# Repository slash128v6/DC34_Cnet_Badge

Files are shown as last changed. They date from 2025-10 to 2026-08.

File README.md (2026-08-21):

# DC34 CompuNet Badge - Malware Scan Tool 3000

Join CompuNet Critical Start at Defcon!

> [!TIP]
> **THIS SPACE FOR LEASE - CALL 702-263-9744 **

# Section 1: Hardware Assembly

1.	Verify inventory:

| Qty	| Description |
|---|---|
|1	|PCB |
|1	|ESP32 Dev Module |
|1	|Round LCD Display |
|1	|RFID Reader |
|1	|Micro SD Card Reader |
|1	|Micro SD Card |
|1	|Slide Switch |
|1	|Schottky Diode |
|1	|RGB LED |
|1	|6 Pin SAO Female Header |
|1	|Battery Holder |
|4	|AAA Batteries |
|1	|Foam Tape |
|1  |3d Printed Stand |
|5  |3d Printed "Slides" |
|5  |RFID Sticker Tags |

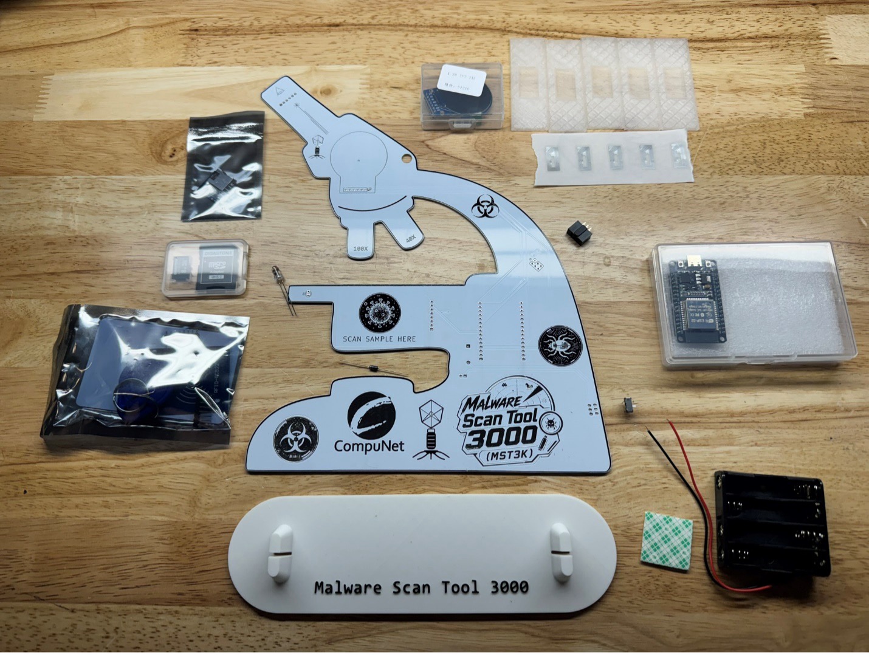
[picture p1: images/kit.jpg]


2.	If you haven't, please download the repo for documentation and code:

[https://github.com/slash128v6/DC34_Cnet_Badge](https://github.com/slash128v6/DC34_Cnet_Badge)

3.	Bend the legs on the Schottky diode and solder on the back side of the PCB. Note the polarity band. Trim the leads on the front of the PCB.

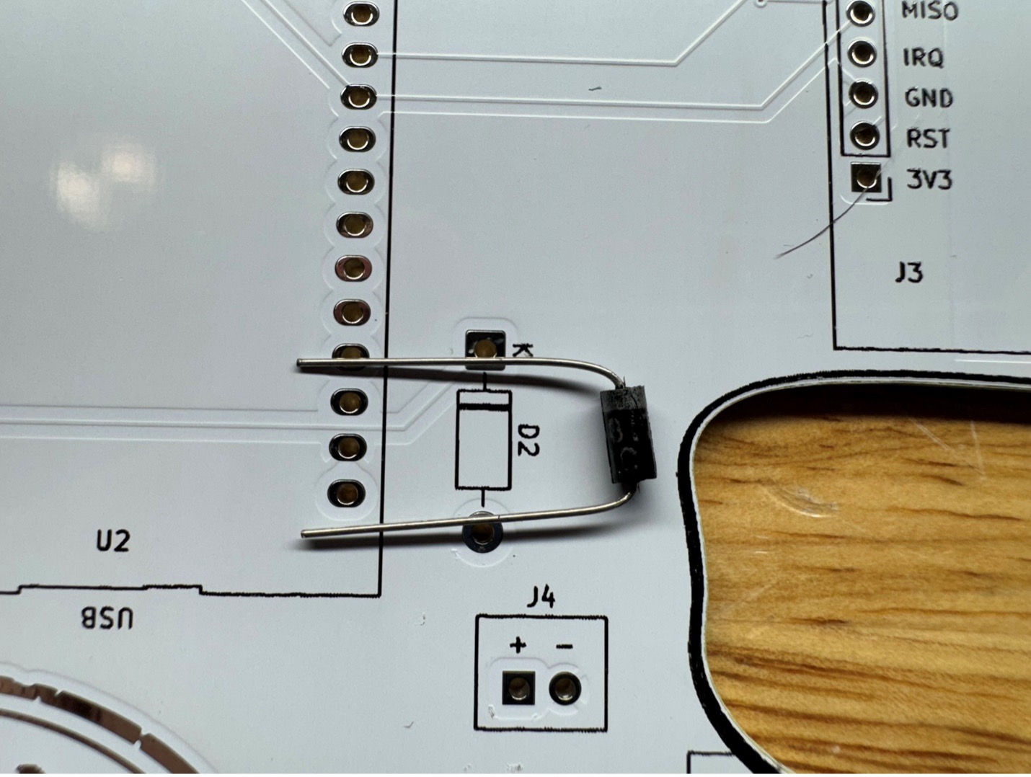
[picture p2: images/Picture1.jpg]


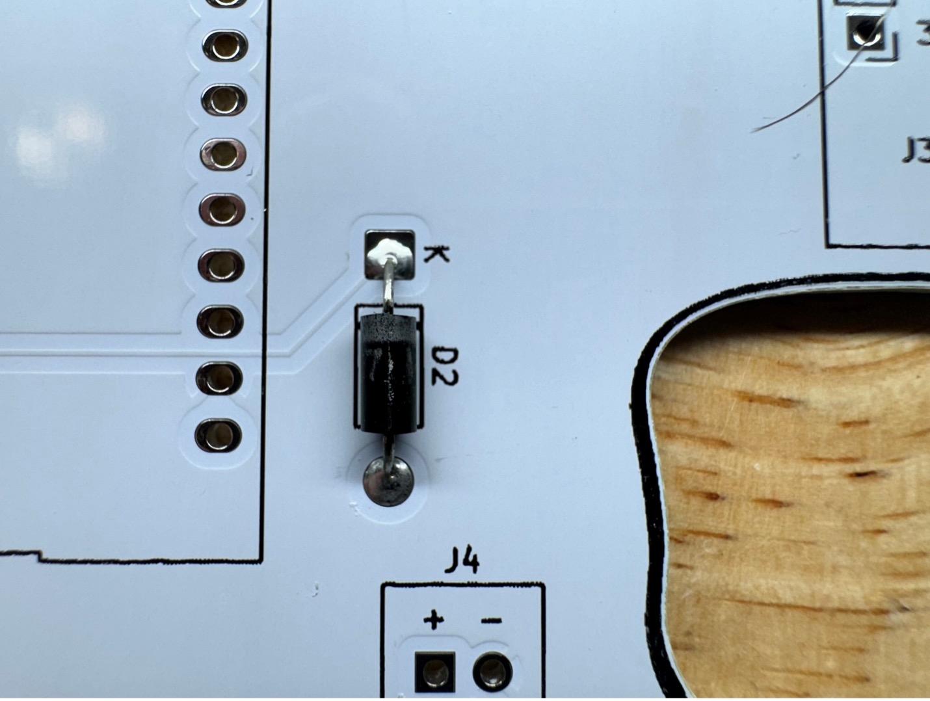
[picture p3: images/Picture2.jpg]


4.	Solder the slide switch on the back of the PCB

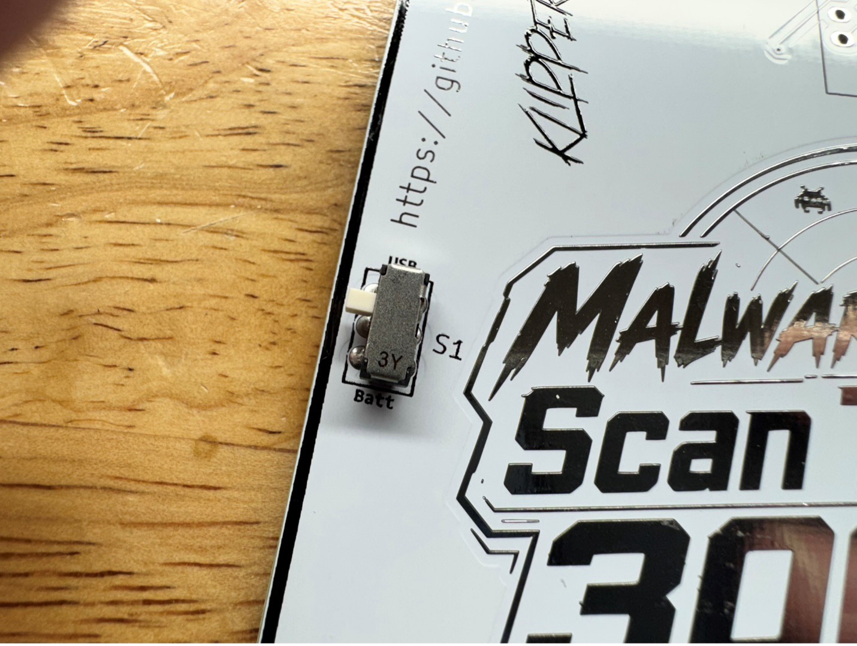
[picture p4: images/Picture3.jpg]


5.	Solder the short side of the pin header to the Micro SD Card Reader as shown:

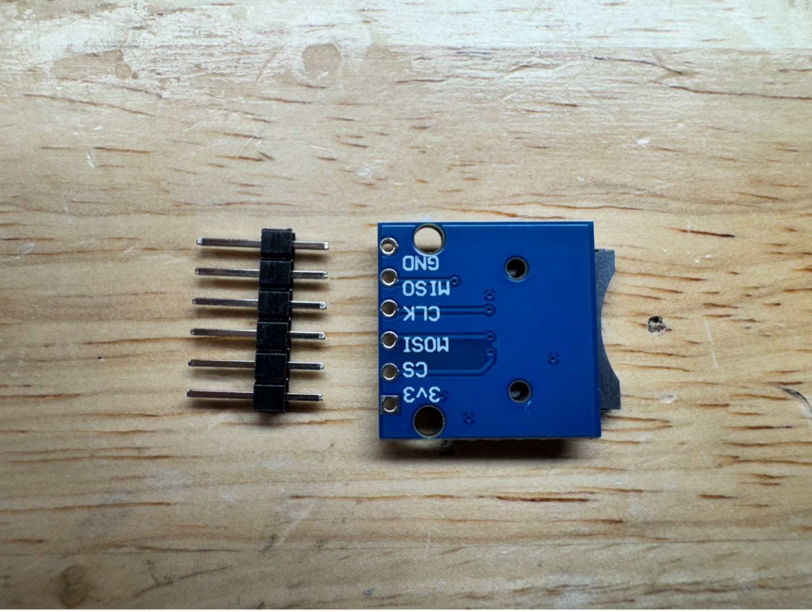
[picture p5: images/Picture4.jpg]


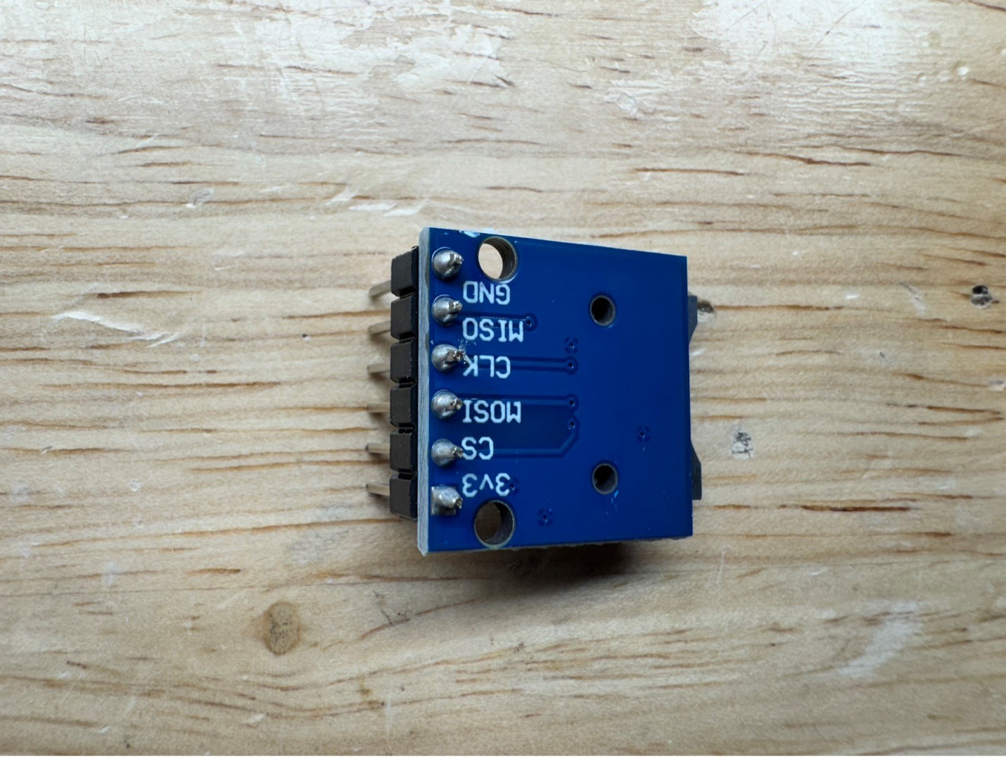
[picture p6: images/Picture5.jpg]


6.	Solder the Micro SD Card Reader to the back of the PCB as shown:

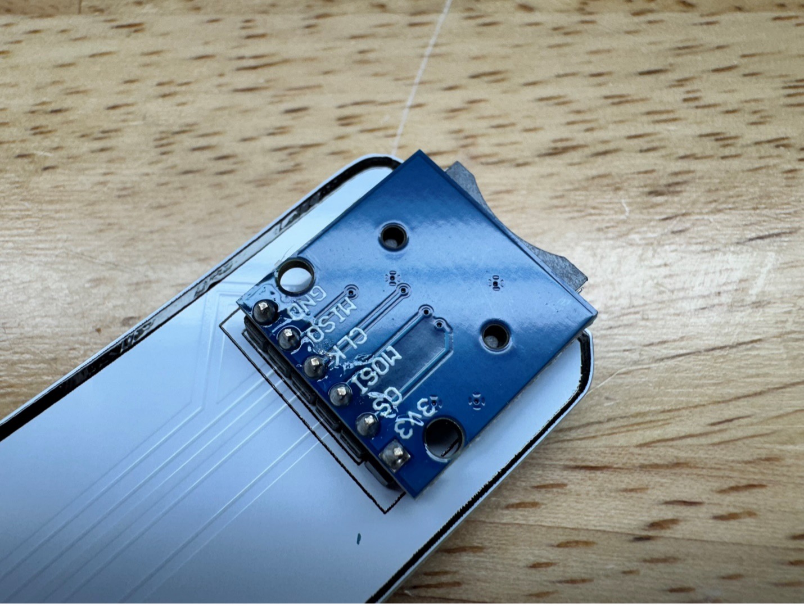
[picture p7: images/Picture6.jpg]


7.	Solder the short side of the pin header to the RFID Reader as shown:

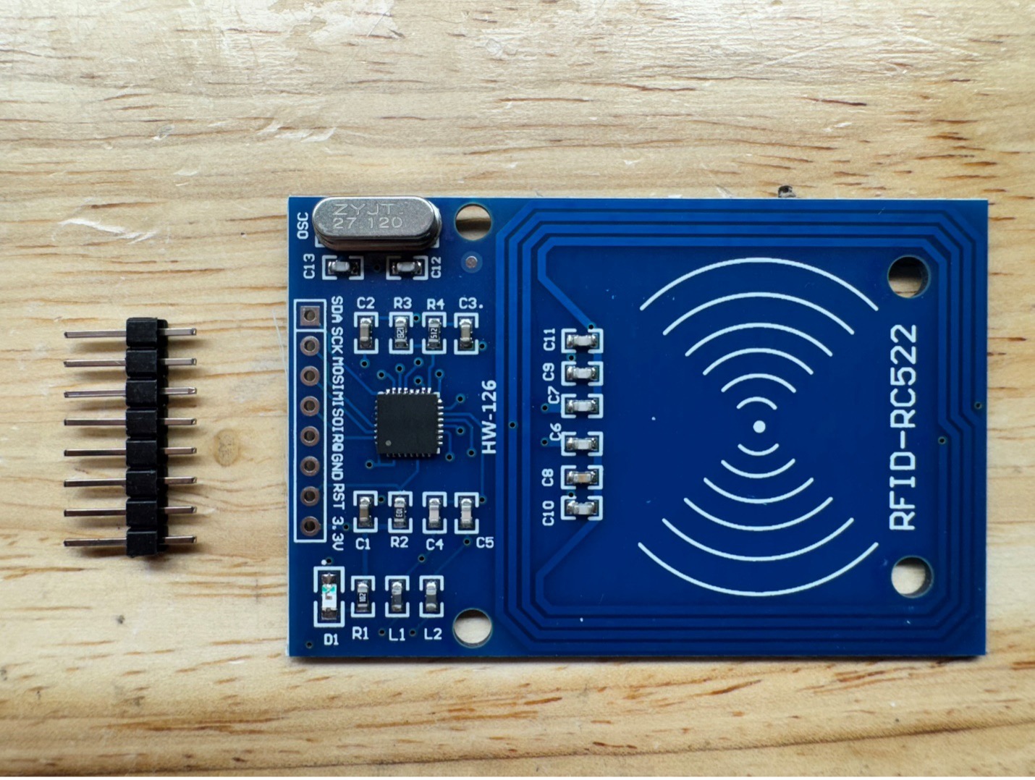
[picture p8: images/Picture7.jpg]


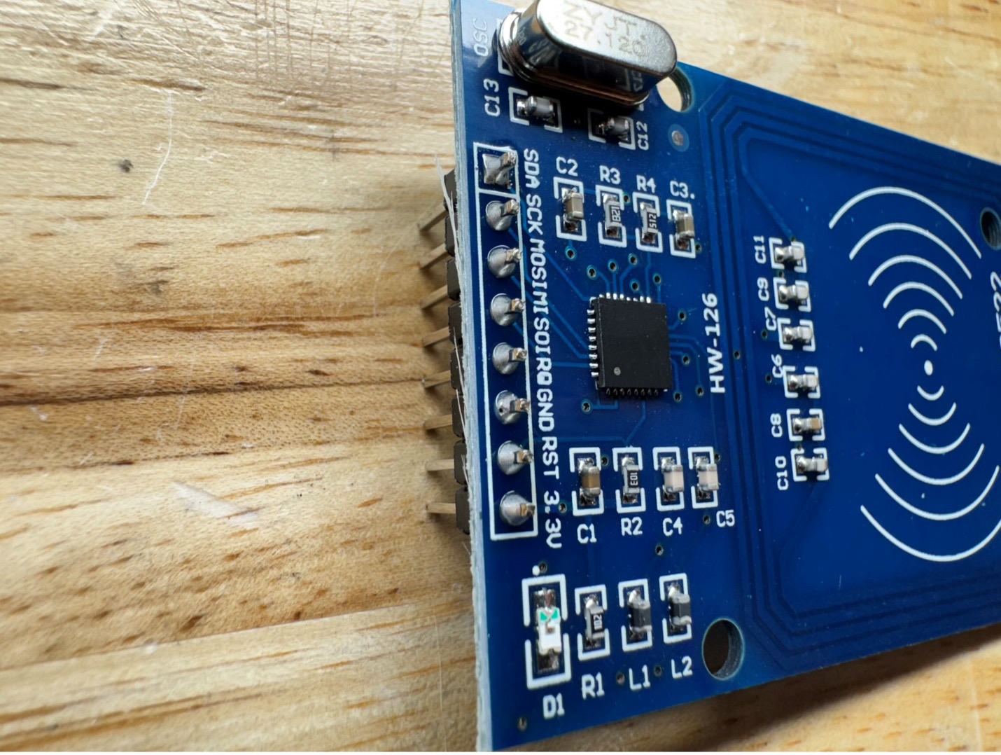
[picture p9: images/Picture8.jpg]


8.  Solder the RFID Reader to the back of the PCB as shown:

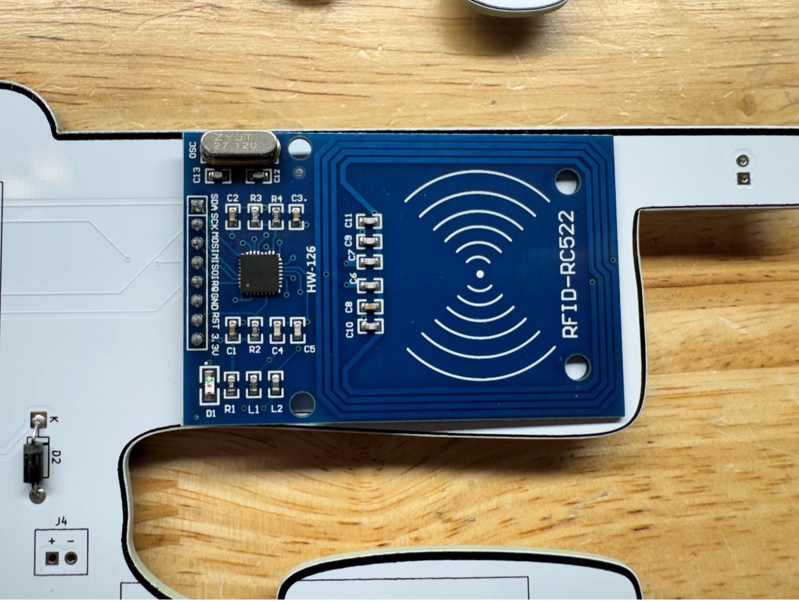
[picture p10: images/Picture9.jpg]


9.  Solder the ESP32 Dev Module to the back of the PCB noting the USB port is at the bottom:

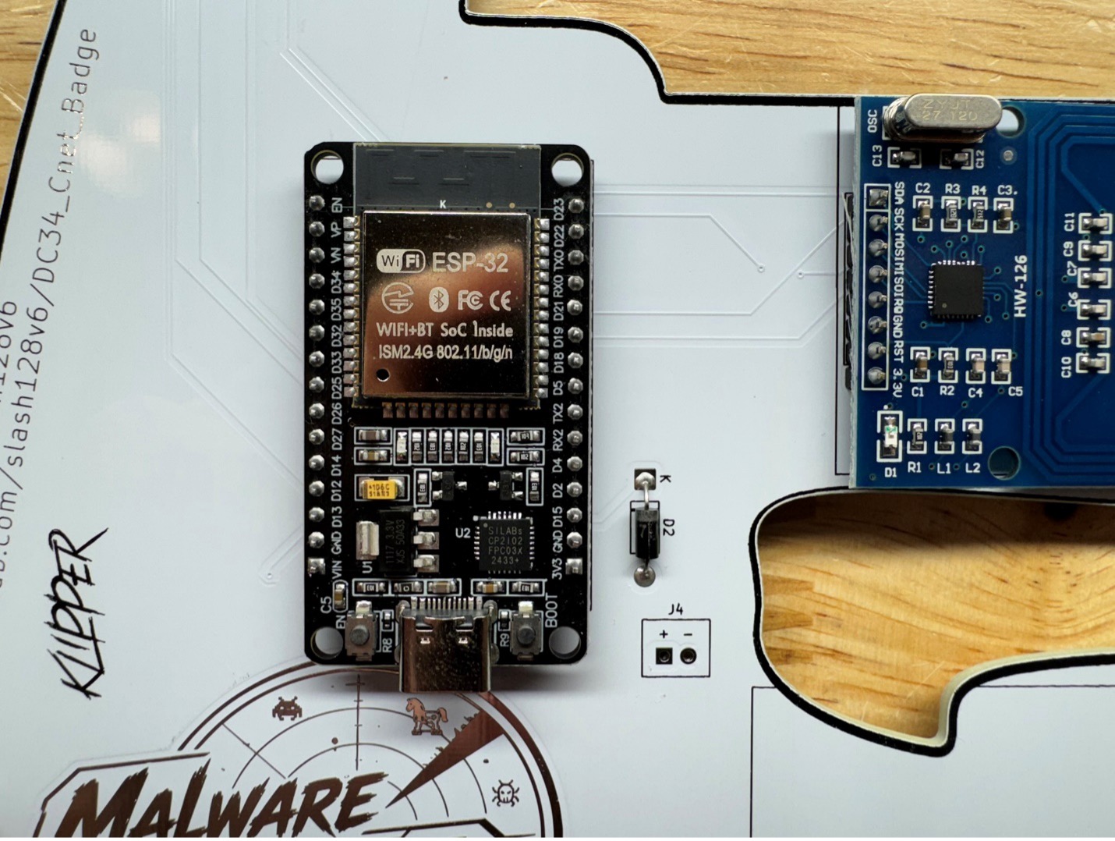
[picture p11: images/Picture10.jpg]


10.	Solder the 6 Pin SAO Header to the front of the PCB with the bump facing upward as shown:

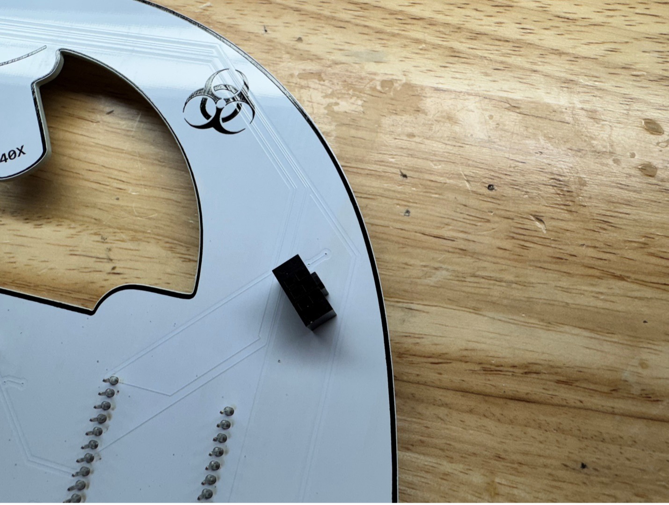
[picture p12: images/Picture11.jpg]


11.	Solder the Round LCD Display to the front of the PCB:

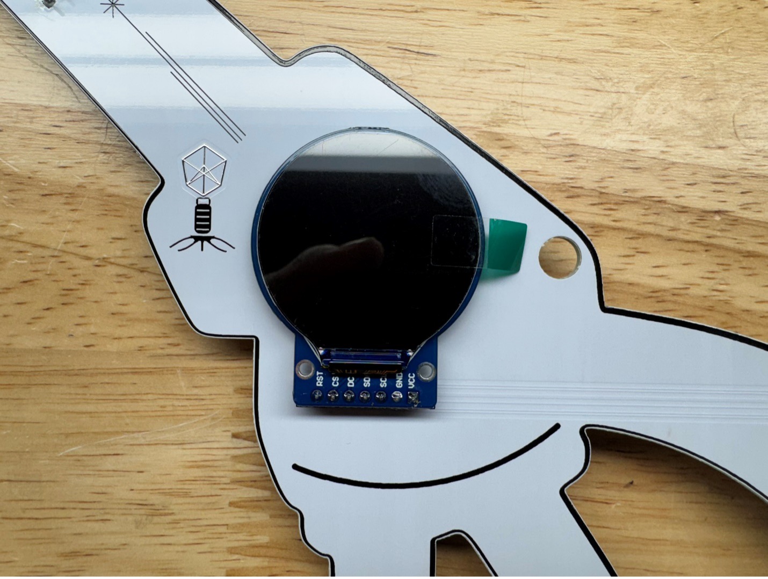
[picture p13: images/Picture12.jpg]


> [!TIP]
> According to Matt Lorimer, it's important to leave extra length on the LED so it can be bent over after soldering (see the next picture).

> [!WARNING]
> Failure to heed Matt's advice will make him cranky and your LED will stand straight out like a rogue ear hair.

> [!NOTE]
> If you ignore Matt and accidentally offend him, amends can be made with a chocolate milk tribute. 

12.	Solder the RGB LED “stage light” through the front of the PCB with the shorter leg into the square hole and bend towards the microscope stage as shown and trim the excess leads from the back to avoid clothing snags:

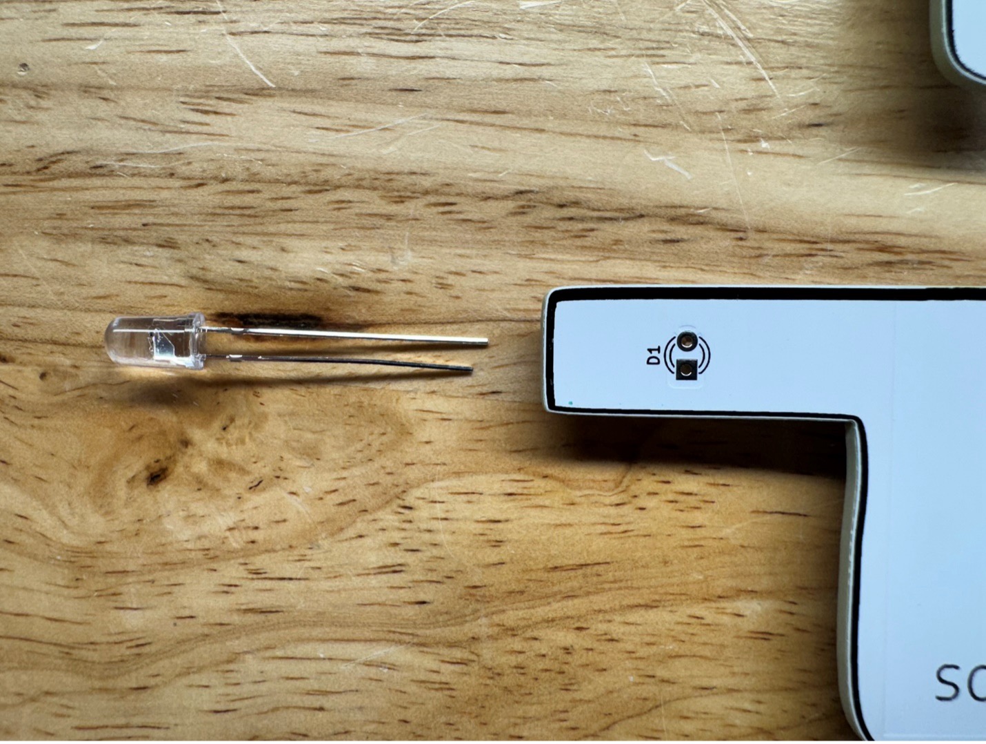
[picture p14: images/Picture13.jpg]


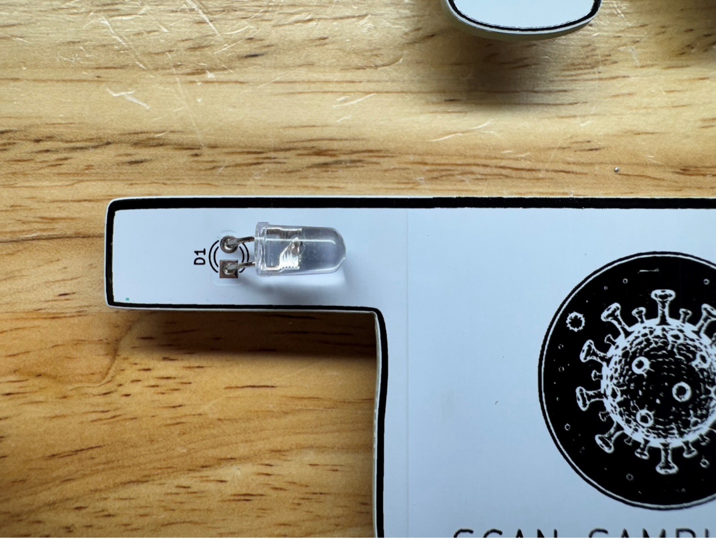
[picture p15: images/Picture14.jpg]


13. Use the double-sided foam tape to attach the 4x AAA battery holder to the rear of the PCB and solder the leads red to (+) and black to (-):

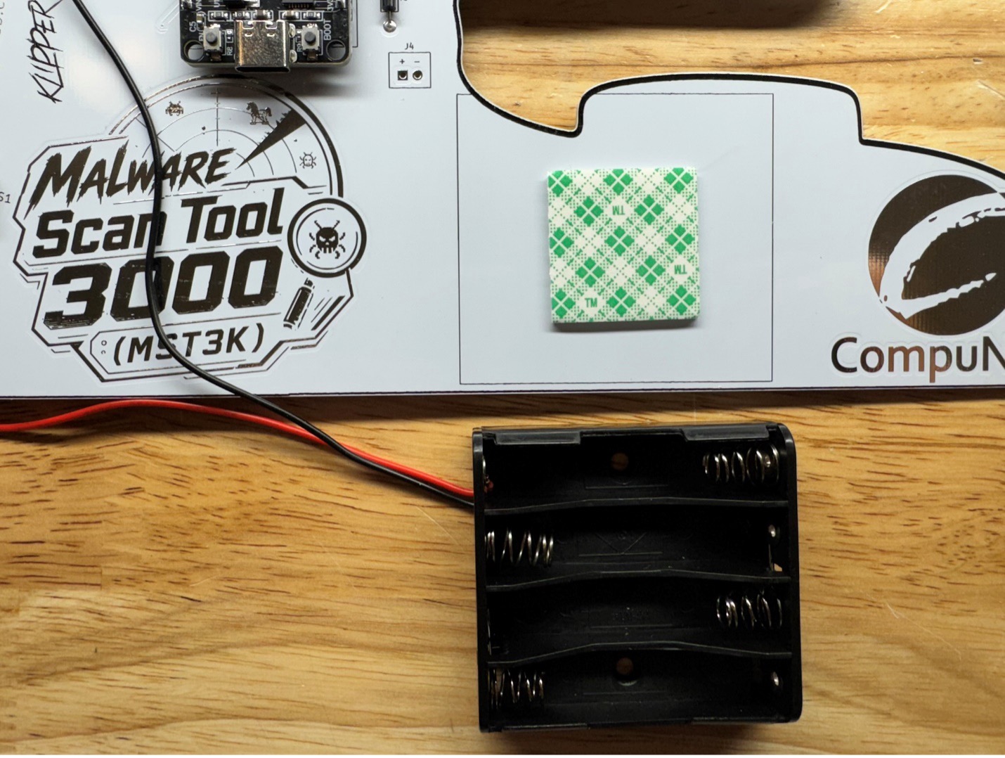
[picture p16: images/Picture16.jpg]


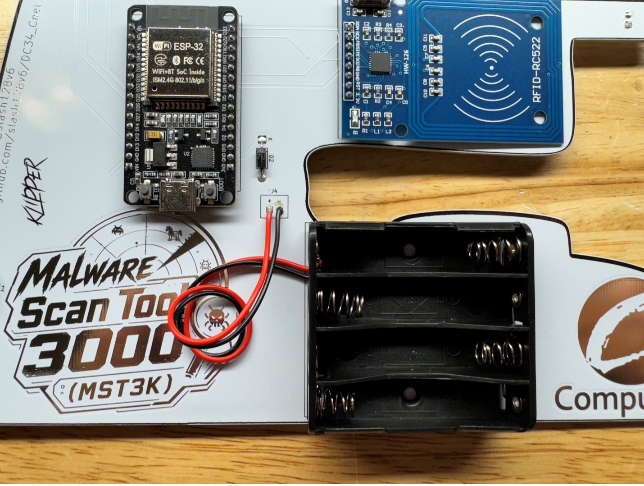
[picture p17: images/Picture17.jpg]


14.	Attach the RFID Tag Stickers in the cavity of the 3D Printed Slides:

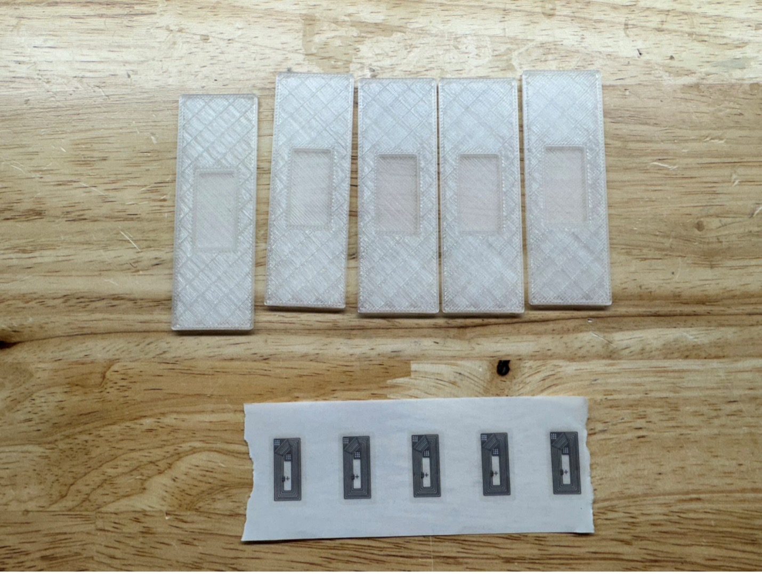
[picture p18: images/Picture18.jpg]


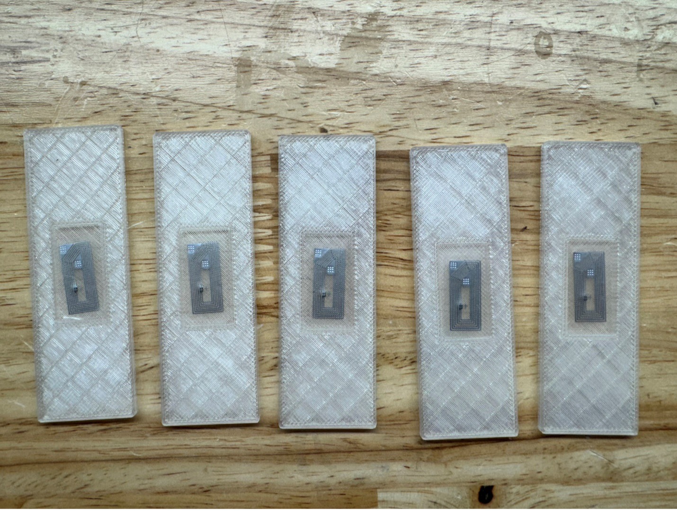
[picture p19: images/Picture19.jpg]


15.	Copy the SD Card Contents from the GitHub repository folder to the Micro SD Card (ignore the System Volume Information folder):

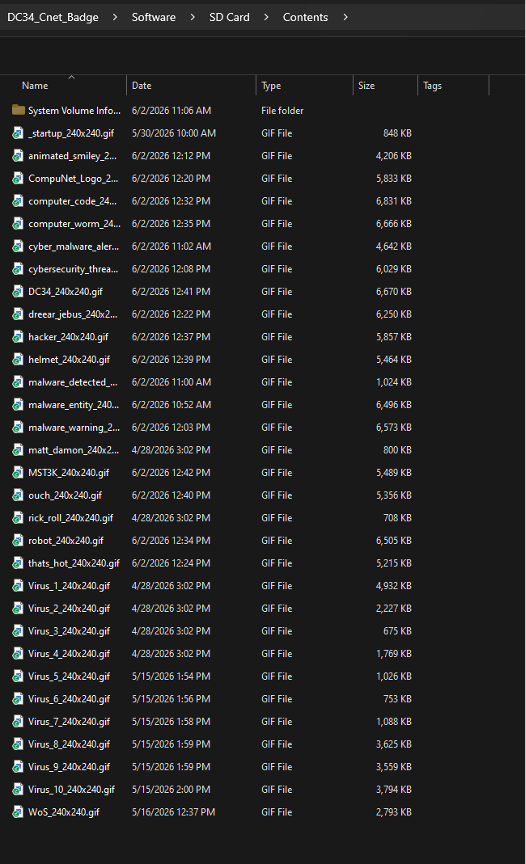
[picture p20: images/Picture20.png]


16. Insert the Micro SD Card into the Micro SD Card Reader with the label facing the front of the badge:

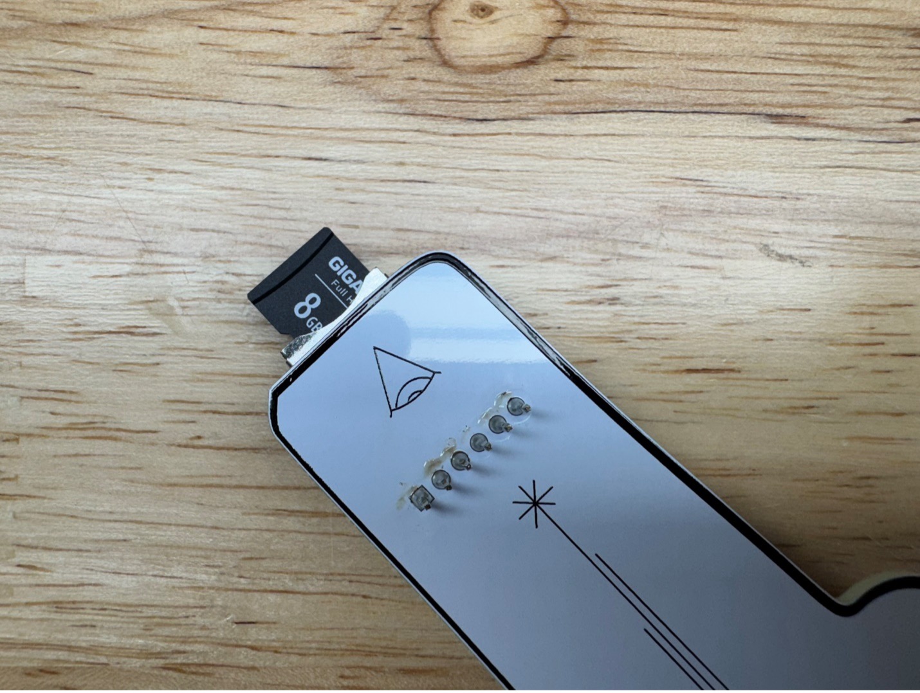
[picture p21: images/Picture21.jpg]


17.	Locate the ESP32 Driver installer in the DC34_Cnet_Badge\Software\ESP32 Driver\CP210x_VCP_Windows\CP210x_VCP_Windows folder. Right-click the CP210xVCPInstaller_x64.exe driver installer and “Run as administrator”:

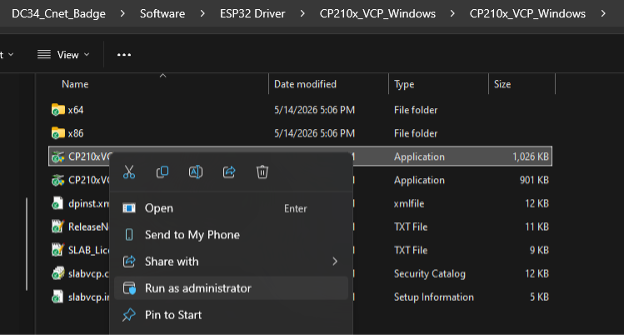
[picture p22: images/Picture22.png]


18. Open the DC34_Cnet_Badge.ino file in the DC34_Cnet_Badge\Software\DC34_Cnet_Badge folder and open in Arduino IDE:

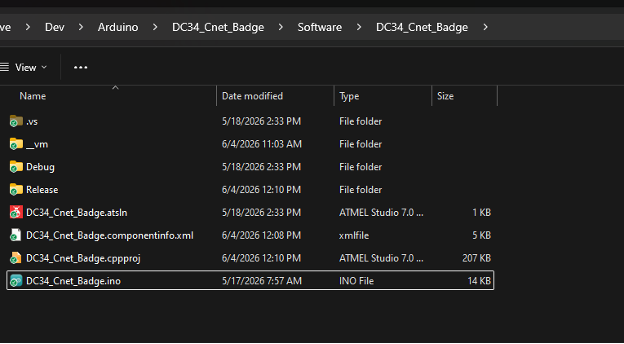
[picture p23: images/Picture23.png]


19.	Add the ESP32 Board URL in Arduino Preferences:

https://espressif.github.io/arduino-esp32/package_esp32_index.json

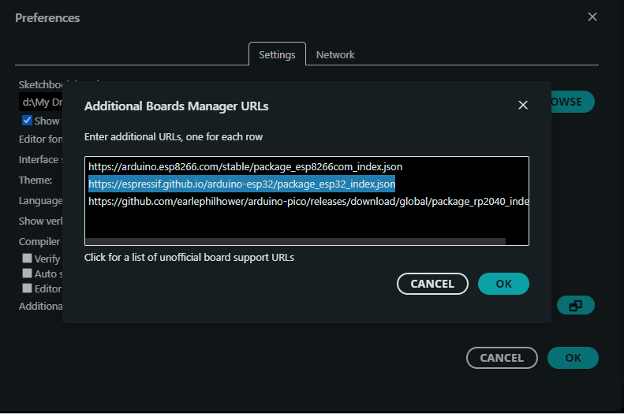
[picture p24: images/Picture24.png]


20.	Install “esp32 by Espressif Systems” in Boards Manager:

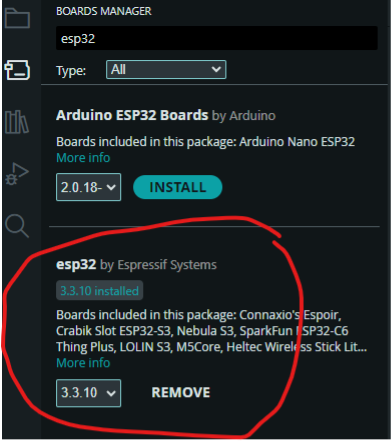
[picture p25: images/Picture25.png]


21. Install the following libraries in Library Manager
a.	Adafruit GFX Library by Adafruit
b.	Adafruit GC9A01A by Adafruit
c.	AnimatedGIF by Larry Bank
d.	MFRC522 by GitHubCommunity
e.	SD by Arduino, Sparkfun
f.	Adafruit SPIFlash by Adafruit

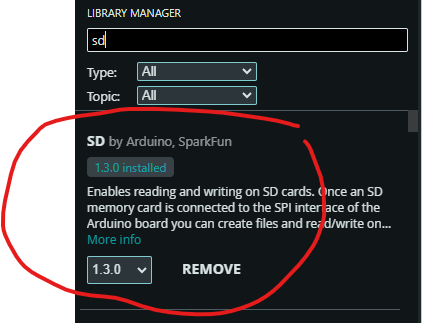
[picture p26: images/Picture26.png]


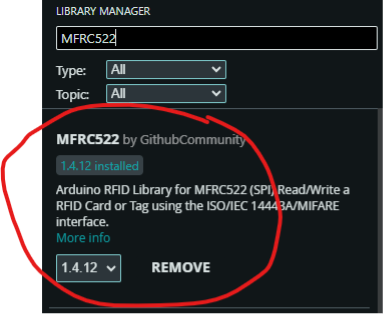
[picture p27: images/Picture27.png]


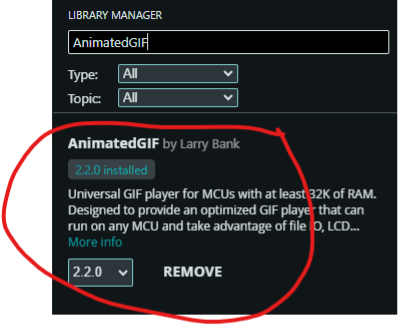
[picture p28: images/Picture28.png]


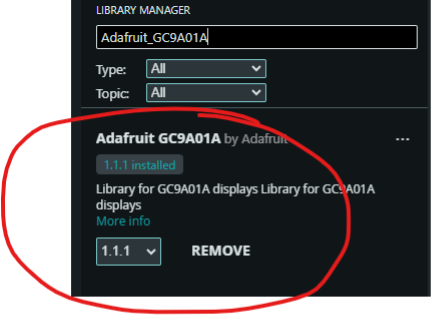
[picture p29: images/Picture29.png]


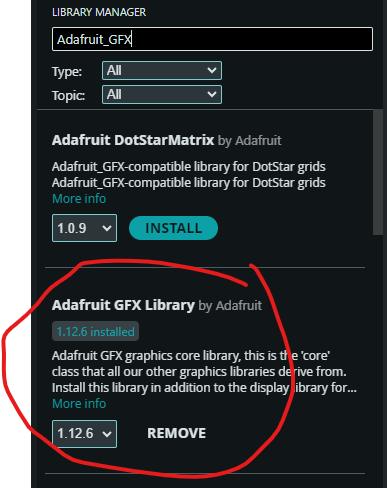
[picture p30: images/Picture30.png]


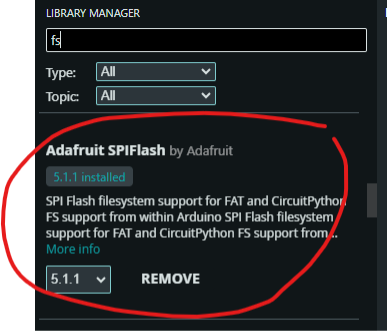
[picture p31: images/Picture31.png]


22. Set the switch on the back of the badge to “USB”. Connect a USB-C cable to the ESP32 module on the back of the badge to your computer. In Arduino IDE select “ESP32 Dev Module – esp32” on the detected COM port:

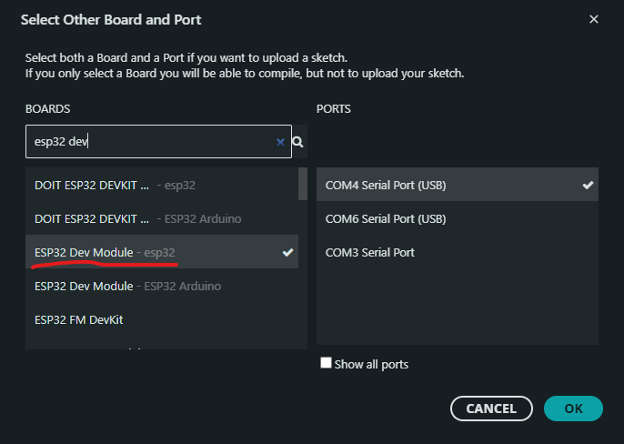
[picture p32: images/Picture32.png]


23. Click the Upload button to flash the badge:

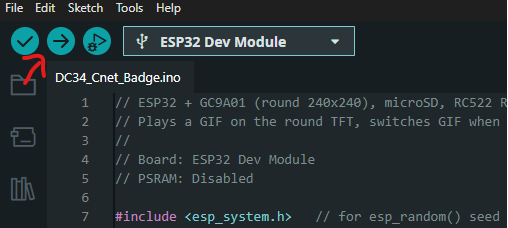
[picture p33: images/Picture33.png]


24. If all went well then you should see the badge logo on the Round LCD Display:



25. “Scan” the slides (or other RFID tags, hotel key cards, have fun!) on the sample area on the front of the badge and watch the display. There are several more images than the 5 slides that were included so share and trade with your friends to unlock all the images!

26. Attach a lanyard if you want to wear it:



27. Or slide the badge into the stand if you want to display it:



# SAO

1. Your SAO badge kit should contain the following components:

| Qty	| Description |
|---|---|
|1	|PCB |
|1	|6 Pin SAO Male Header |
|4	|RGB LEDs|

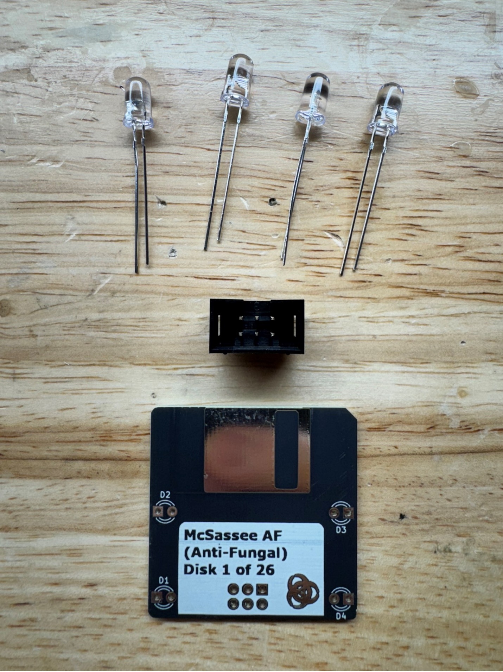
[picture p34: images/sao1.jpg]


2.	Solder the 6 Pin SAO Male Header to the back of the PCB with the notch matching the outline on the PCB:

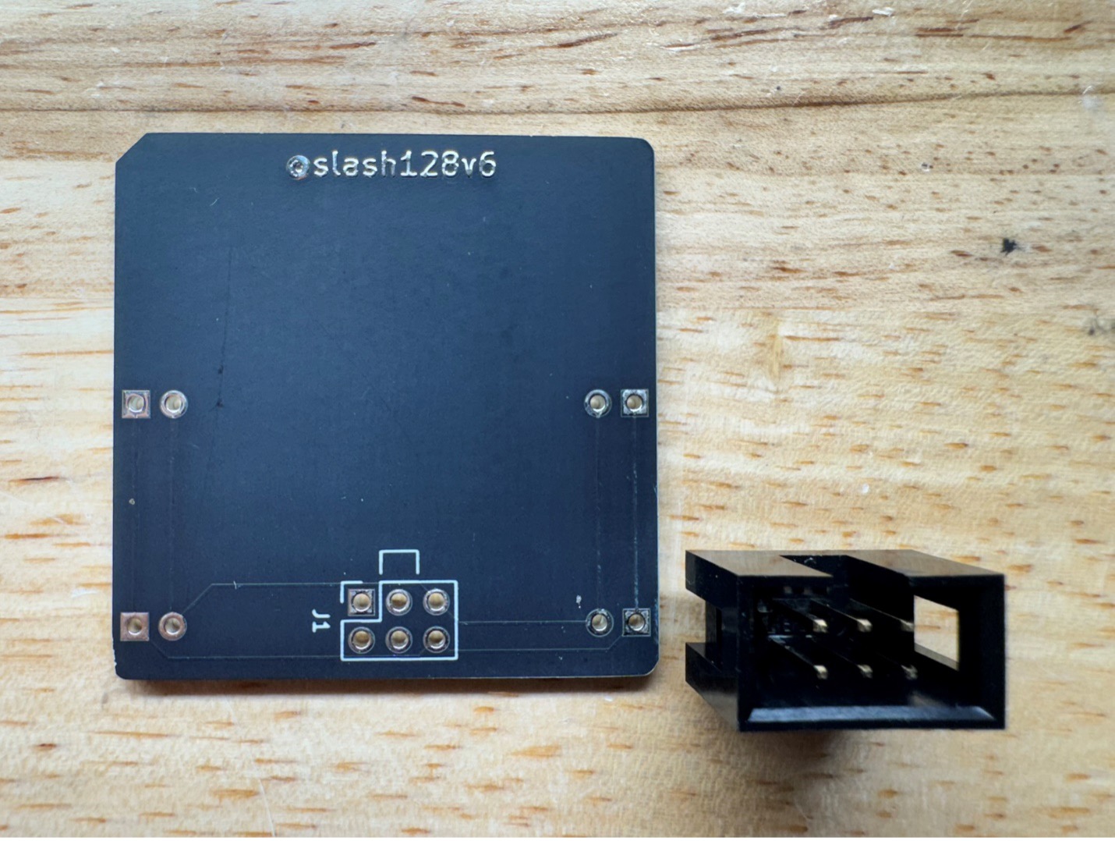
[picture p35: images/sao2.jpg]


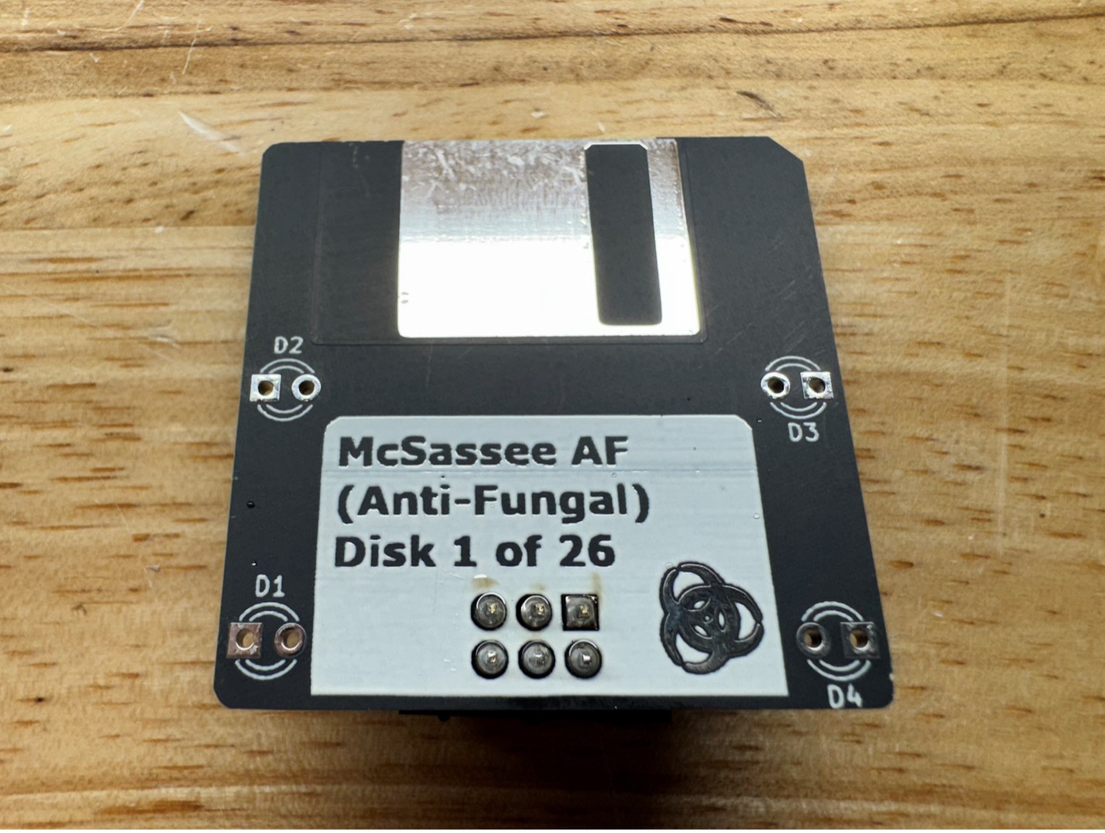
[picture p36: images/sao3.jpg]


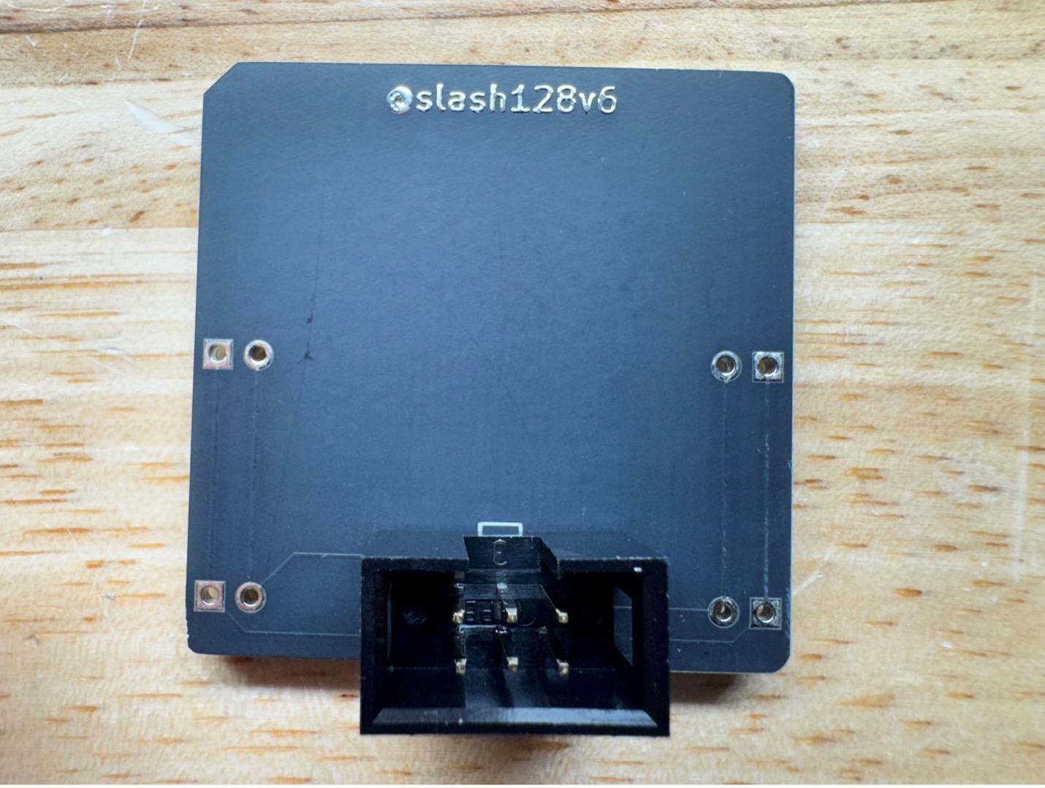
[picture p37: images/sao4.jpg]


3. 	Solder the RGB LEDs through the front of the PCB with the short leads in the square holes and trim the leads on the back:

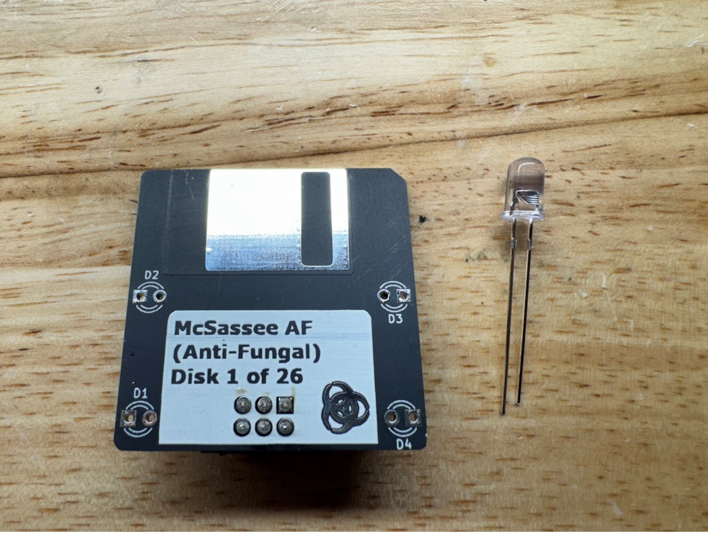
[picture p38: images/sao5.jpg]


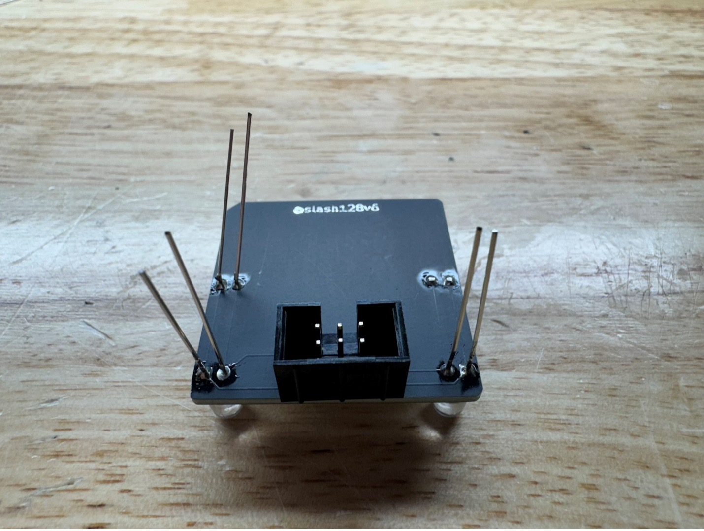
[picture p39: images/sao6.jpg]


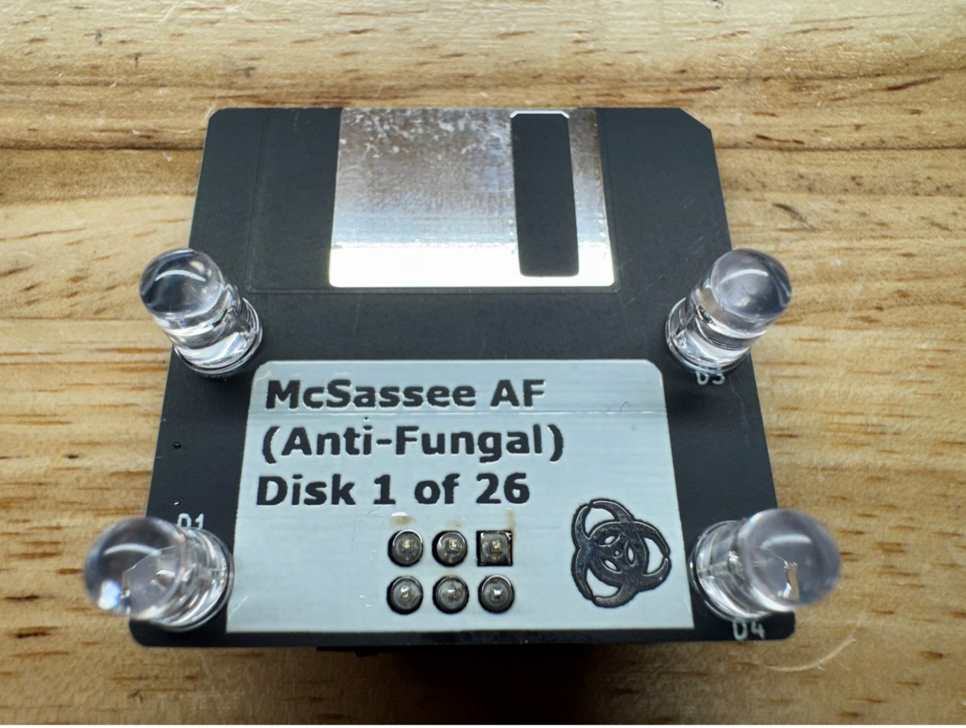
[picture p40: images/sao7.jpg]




4. 	Connect to the 6 Pin SAO Female Header on the main badge and the LEDs should light up!



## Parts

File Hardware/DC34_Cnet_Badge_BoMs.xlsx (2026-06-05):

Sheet: DC34_Cnet_Badge
Part | Badge Qty | Unit Cost | Extended Cost | Supplier | Pack Qty | Pack Cost | Order Qty | Order Cost | Order Link
PCB | 1 | $9.69 | $9.69 | PCBWay | 1 | $9.69 | 75 | $726.70 | https://www.pcbway.com/QuickOrderOnline.aspx
ESP32 | 1 | $5.66 | $5.66 | Amazon | 3 | $16.99 | 25 | $424.75 | https://www.amazon.com/dp/B0D8T53CQ5/?coliid=I3VJO6C85UICKN&colid=12Q39W8V03L12
SD Card Reader | 1 | $1.17 | $1.17 | Amazon | 6 | $6.99 | 13 | $90.87 | https://www.amazon.com/dp/B0BV8ZQ81F/?coliid=I10OQA73D14EXB&colid=12Q39W8V03L12
SD Card | 1 | $9.49 | $9.49 | Amazon | 2 | $18.98 | 38 | $721.24 | https://www.amazon.com/dp/B0858FBL8V/?coliid=I2GIA4ELW55THL&colid=12Q39W8V03L12
4x AAA Battery Holder | 1 | $1.33 | $1.33 | Amazon | 6 | $7.99 | 13 | $103.87 | https://www.amazon.com/dp/B01GVDGA5S/?coliid=IVPLVKM4NMG9N&colid=12Q39W8V03L12
4x AAA Batteries | 4 | $0.30 | $1.20 | Amazon | 100 | $29.99 | 3 | $89.97 | https://www.amazon.com/dp/B01B8R6V2E/?coliid=I3C19CNAWGVTLF&colid=12Q39W8V03L12
RFID Reader | 1 | $2.00 | $2.00 | Amazon | 5 | $9.99 | 15 | $149.85 | https://www.amazon.com/dp/B09P5WJWLN/?coliid=I1FBV7RBIW4U2T&colid=12Q39W8V03L12
Display | 1 | $4.40 | $4.40 | Amazon | 5 | $21.99 | 15 | $329.85 | https://www.amazon.com/dp/B0DCBM8KV1/?coliid=I3OQX6ILNUIJUC&colid=12Q39W8V03L12
RFID Tags | 5 | $0.30 | $1.50 | Amazon | 50 | $14.99 | 8 | $119.92 | https://www.amazon.com/dp/B0CMXHWTYH/?coliid=I1O4MENNAUG3KH&colid=12Q39W8V03L12
Schottky Diode Diode | 1 | $0.07 | $0.07 | Amazon | 100 | $6.99 | 1 | $6.99 | https://www.amazon.com/dp/B079KDQQPD/?coliid=IDH1L3DI3CNBL&colid=12Q39W8V03L12
Foam tape | 1 | $0.07 | $0.07 | Amazon | 100 | $6.99 | 1 | $6.99 | https://www.amazon.com/dp/B0CCS11XFL/?coliid=I3N0PGN9F5PV51&colid=12Q39W8V03L12
SAO Header | 1 | $0.63 | $0.63 | DigiKey | 1 | $0.63 | 75 | $47.25 | https://www.digikey.com/en/products/detail/sullins-connector-solutions/SFH11-NBPC-D03-ST-BK/4558818
Switch | 1 | $1.37 | $1.37 | DigiKey | 1 | $1.37 | 75 | $102.75 | https://www.digikey.com/en/products/detail/nidec-components/CL-SB-22C-11/3507850
RGB LED - Slow Cycle - 3mm | 1 | $0.60 | $0.60 | DigiKey | 1 | $0.60 | 75 | $45.00 | https://www.digikey.com/en/products/detail/sparkfun-electronics/11448/5673782
Static Bag | 1 | $0.53 | $0.53 | DigiKey | 1 | $0.53 | 75 | $39.75 | https://www.digikey.com/en/products/detail/scs/3001012/1621604
 |  |  | $39.70 | Cost Per Badge |  |  |  | $3005.75 | Total Order Cost
 |  |  | 75 | Qty - Master
 |  |  | $2977.78 | Total Badges Cost

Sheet: DC34_Cnet_Badge - Alt LED
Part | Badge Qty | Unit Cost | Extended Cost | Supplier | Pack Qty | Pack Cost | Order Qty | Order Cost | Order Link
PCB | 1 | $7.86 | $7.86 | PCBWay | 1 | $7.86 | 75 | $726.70 | https://www.pcbway.com/QuickOrderOnline.aspx
ESP32 | 1 | $5.66 | $5.66 | Amazon | 3 | $16.99 | 25 | $424.75 | https://www.amazon.com/dp/B0D8T53CQ5/?coliid=I3VJO6C85UICKN&colid=12Q39W8V03L12
SD Card Reader | 1 | $1.17 | $1.17 | Amazon | 6 | $6.99 | 13 | $90.87 | https://www.amazon.com/dp/B0BV8ZQ81F/?coliid=I10OQA73D14EXB&colid=12Q39W8V03L12
SD Card | 1 | $9.49 | $9.49 | Amazon | 2 | $18.98 | 38 | $721.24 | https://www.amazon.com/dp/B0858FBL8V/?coliid=I2GIA4ELW55THL&colid=12Q39W8V03L12
4x AAA Battery Holder | 1 | $1.33 | $1.33 | Amazon | 6 | $7.99 | 13 | $103.87 | https://www.amazon.com/dp/B01GVDGA5S/?coliid=IVPLVKM4NMG9N&colid=12Q39W8V03L12
4x AAA Batteries | 4 | $0.30 | $1.20 | Amazon | 100 | $29.99 | 3 | $89.97 | https://www.amazon.com/dp/B01B8R6V2E/?coliid=I3C19CNAWGVTLF&colid=12Q39W8V03L12
RFID Reader | 1 | $2.00 | $2.00 | Amazon | 5 | $9.99 | 15 | $149.85 | https://www.amazon.com/dp/B09P5WJWLN/?coliid=I1FBV7RBIW4U2T&colid=12Q39W8V03L12
Display | 1 | $4.40 | $4.40 | Amazon | 5 | $21.99 | 15 | $329.85 | https://www.amazon.com/dp/B0DCBM8KV1/?coliid=I3OQX6ILNUIJUC&colid=12Q39W8V03L12
RFID Tags | 5 | $0.30 | $1.50 | Amazon | 50 | $14.99 | 8 | $119.92 | https://www.amazon.com/dp/B0CMXHWTYH/?coliid=I1O4MENNAUG3KH&colid=12Q39W8V03L12
Schottky Diode Diode | 1 | $0.07 | $0.07 | Amazon | 100 | $6.99 | 1 | $6.99 | https://www.amazon.com/dp/B079KDQQPD/?coliid=IDH1L3DI3CNBL&colid=12Q39W8V03L12
Foam tape | 1 | $0.07 | $0.07 | Amazon | 100 | $6.99 | 1 | $6.99 | https://www.amazon.com/dp/B0CCS11XFL/?coliid=I3N0PGN9F5PV51&colid=12Q39W8V03L12
SAO Header | 1 | $0.63 | $0.63 | DigiKey | 1 | $0.63 | 75 | $47.25 | https://www.digikey.com/en/products/detail/sullins-connector-solutions/SFH11-NBPC-D03-ST-BK/4558818
Switch | 1 | $1.37 | $1.37 | DigiKey | 1 | $1.37 | 75 | $102.75 | https://www.digikey.com/en/products/detail/nidec-components/CL-SB-22C-11/3507850
RGB LED - Slow Cycle - 5mm | 1 | $0.99 | $0.99 | DigiKey | 1 | $0.99 | 75 | $74.25 | https://www.digikey.com/en/products/detail/sparkfun-electronics/11450/5673784
Static Bag | 1 | $0.53 | $0.53 | DigiKey | 1 | $0.53 | 75 | $39.75 | https://www.digikey.com/en/products/detail/scs/3001012/1621604
 |  |  | $38.26 | Cost Per Badge |  |  |  | $3035.00 | Total Order Cost
 |  |  | 75 | Qty - Master
 |  |  | $2869.83 | Total Badges Cost

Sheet: DC34_Cnet_SAO
Part | Badge Qty | Unit Cost | Extended Cost | Supplier | Pack Qty | Pack Cost | Order Qty | Order Cost | Order Link
PCB | 1 | $1.20 | $1.20 | PCBWay | 1 | $1.20 | 75 | $90.27 | https://www.pcbway.com/QuickOrderOnline.aspx
SAO Header | 1 | $0.43 | $0.43 | DigiKey | 1 | $0.43 | 75 | $32.25 | https://www.digikey.com/en/products/detail/w%C3%BCrth-elektronik/61200621621/4846913
RGB LED - Slow Cycle - 3mm | 2 | $0.60 | $1.20 | DigiKey | 1 | $0.60 | 150 | $90.00 | https://www.digikey.com/en/products/detail/sparkfun-electronics/11448/5673782
RGB LED - Fast Cycle - 3mm | 2 | $0.60 | $1.20 | DigiKey | 1 | $0.60 | 150 | $90.00 | https://www.digikey.com/en/products/detail/sparkfun-electronics/11449/5673783
Static Bag | 1 | $0.17 | $0.17 | DigiKey | 1 | $0.17 | 75 | $12.75 | https://www.digikey.com/en/products/detail/scs/30035/3430456
 |  |  | $4.20 | Cost Per Badge |  |  |  | $315.27 | Total Order Cost
 |  |  | 75 | Qty - Master
 |  |  | $315.27 | Total SAOs Cost

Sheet: DC34_Cnet_SAO - Alt LED
Part | Badge Qty | Unit Cost | Extended Cost | Supplier | Pack Qty | Pack Cost | Order Qty | Order Cost | Order Link
PCB | 1 | $1.20 | $1.20 | PCBWay | 1 | $1.20 | 75 | $90.27 | https://www.pcbway.com/QuickOrderOnline.aspx
SAO Header | 1 | $0.43 | $0.43 | DigiKey | 1 | $0.43 | 75 | $32.25 | https://www.digikey.com/en/products/detail/w%C3%BCrth-elektronik/61200621621/4846913
RGB LED - Slow Cycle - 5mm | 4 | $0.99 | $3.96 | DigiKey | 1 | $0.99 | 300 | $297.00 | https://www.digikey.com/en/products/detail/sparkfun-electronics/11450/5673784
Static Bag | 1 | $0.17 | $0.17 | DigiKey | 1 | $0.17 | 75 | $12.75 | https://www.digikey.com/en/products/detail/scs/30035/3430456
 |  |  | $5.76 | Cost Per Badge |  |  |  | $432.27 | Total Order Cost
 |  |  | 75 | Qty - Master
 |  |  | $432.27 | Total SAOs Cost

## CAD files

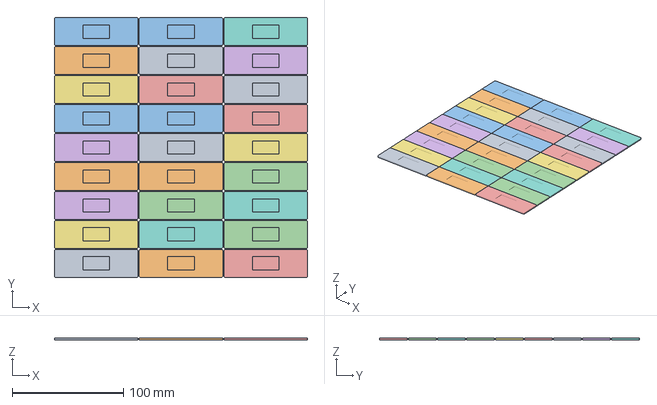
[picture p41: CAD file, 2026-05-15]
Hardware/3D Printed Parts/Slides/Slide-Body.3mf
227.0 x 233.0 x 2.00 mm
Slide-Body.stl x 27

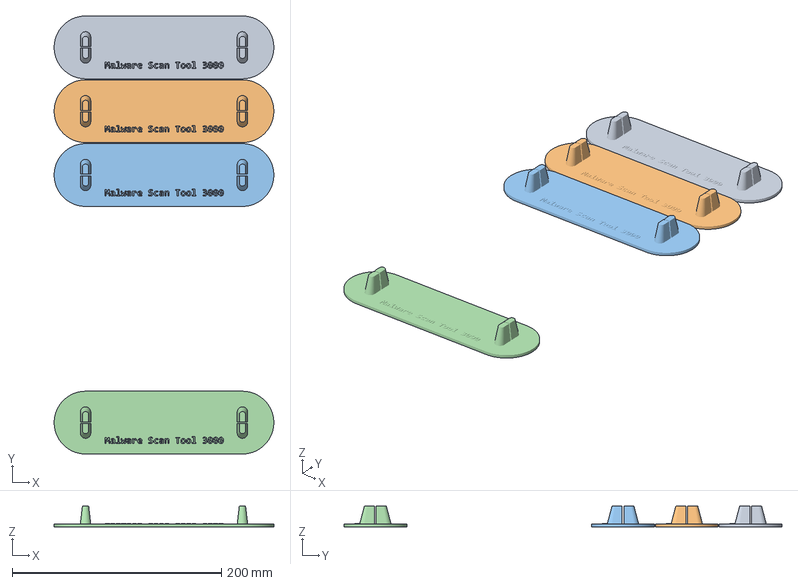
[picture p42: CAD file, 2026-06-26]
Hardware/3D Printed Parts/Stand/DC34_Stand-Body.3mf
210.0 x 418.7 x 20.0 mm
DC34_Stand-Body.stl x 4

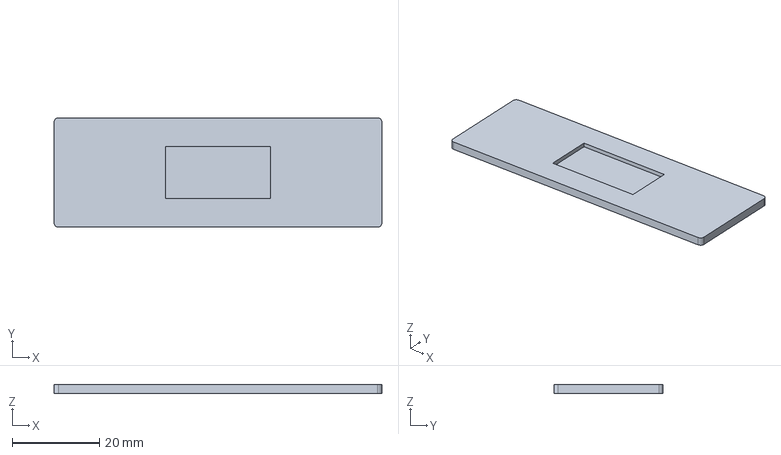
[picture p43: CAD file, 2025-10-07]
Hardware/3D Printed Parts/Slides/Slide.FCStd
75.0 x 25.0 x 2.00 mm

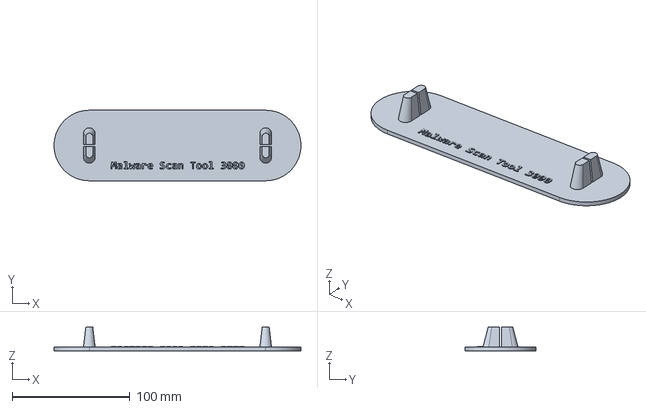
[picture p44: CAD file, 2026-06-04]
Hardware/3D Printed Parts/Stand/DC34_Stand.FCStd
210.0 x 60.0 x 20.0 mm

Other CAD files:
Hardware/3D Printed Parts/Slides/Slide-Body.stl
Hardware/3D Printed Parts/Stand/DC34_Stand-Body.stl
Hardware/3D Printed Parts/Stand/DC34_Stand.blend

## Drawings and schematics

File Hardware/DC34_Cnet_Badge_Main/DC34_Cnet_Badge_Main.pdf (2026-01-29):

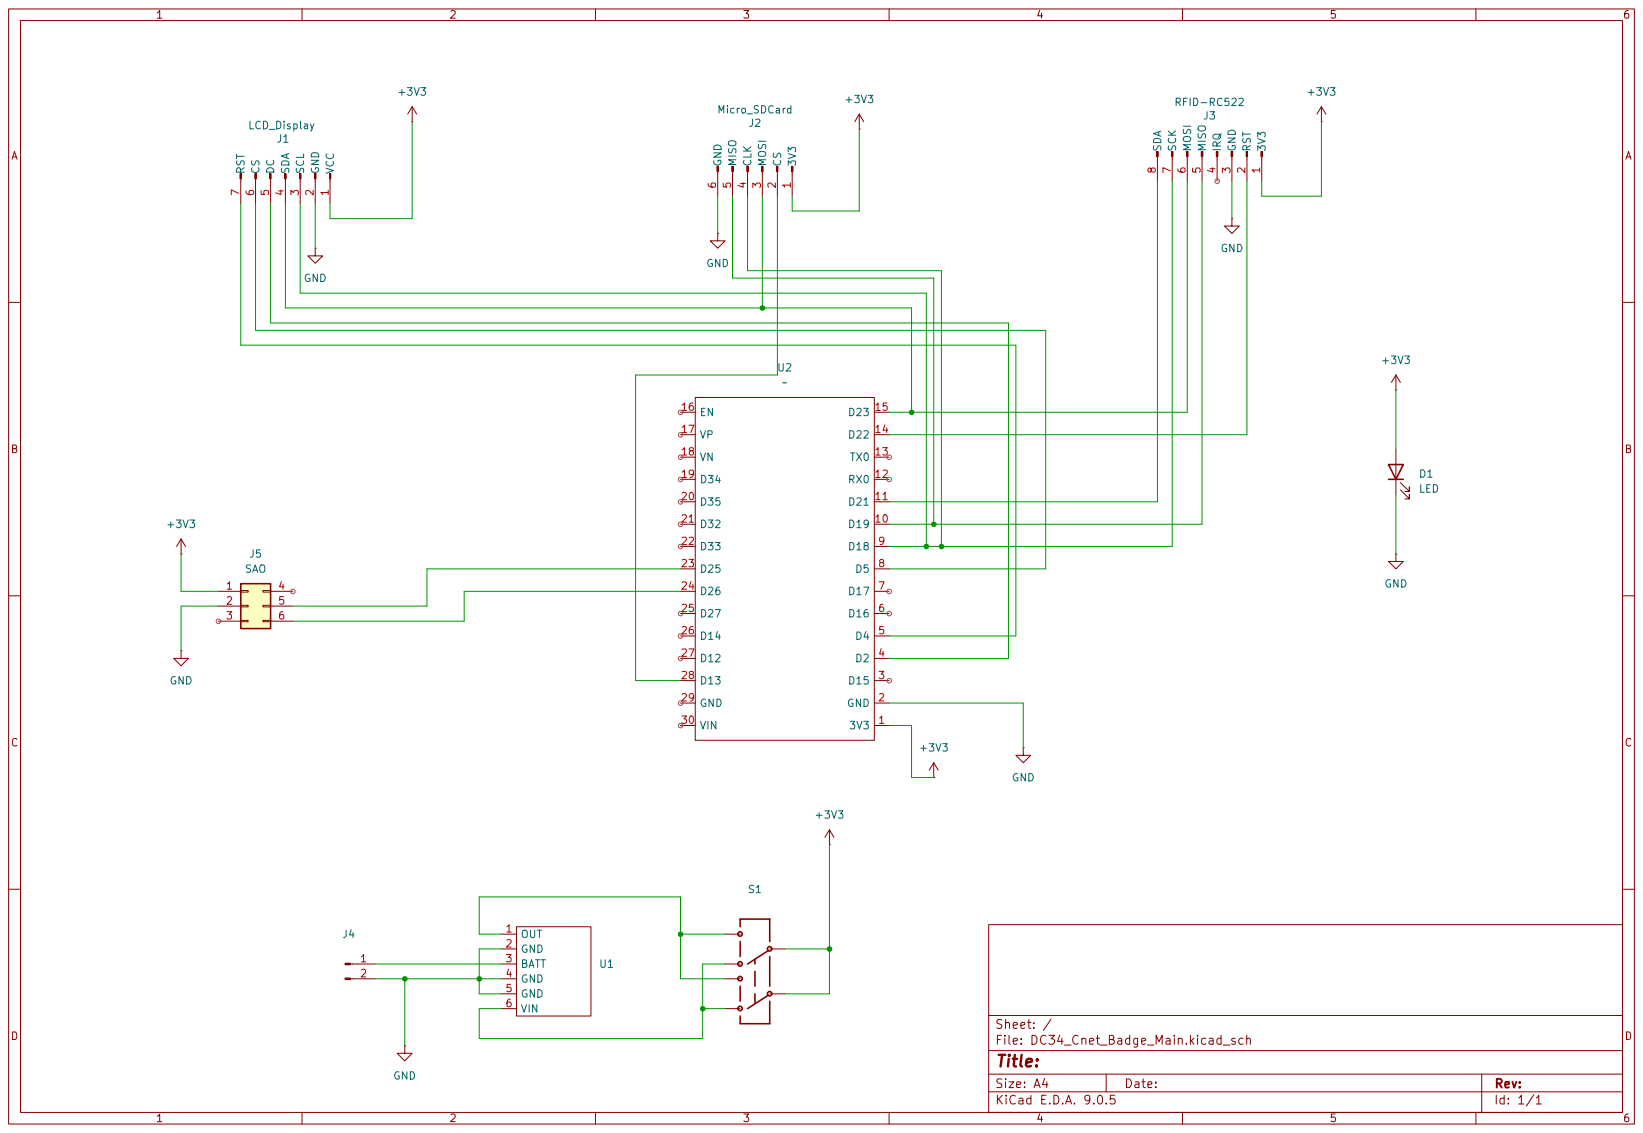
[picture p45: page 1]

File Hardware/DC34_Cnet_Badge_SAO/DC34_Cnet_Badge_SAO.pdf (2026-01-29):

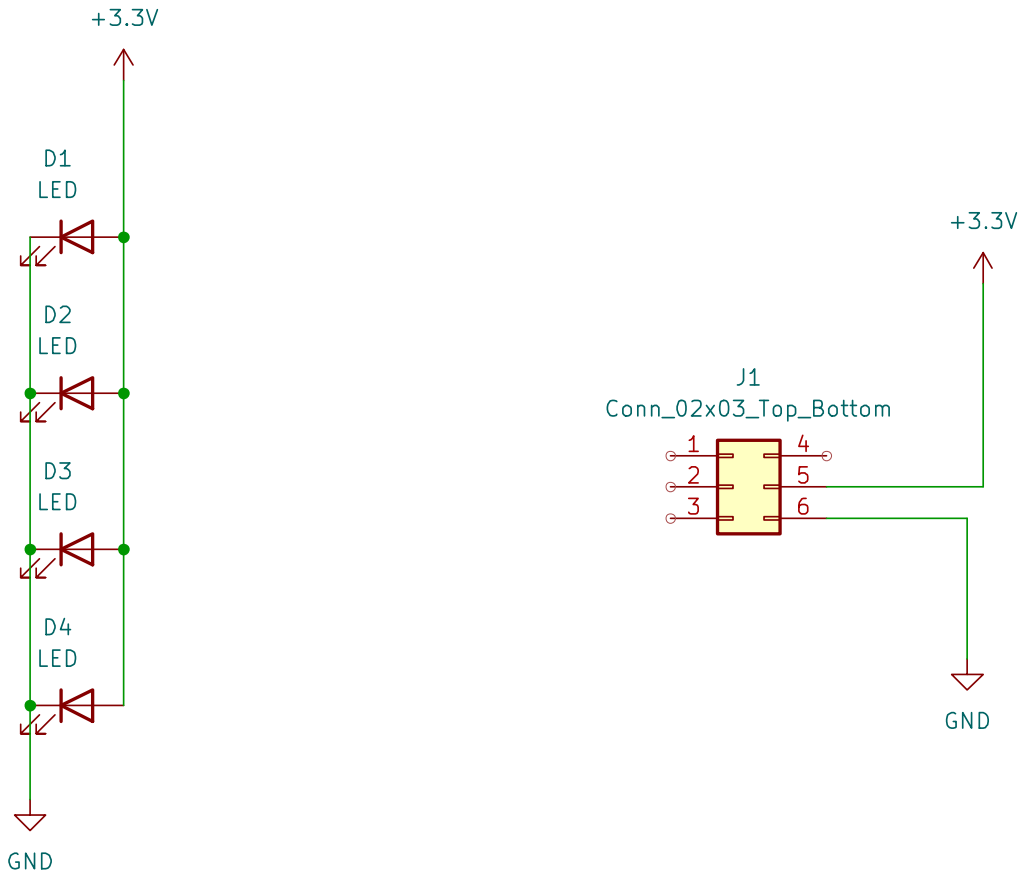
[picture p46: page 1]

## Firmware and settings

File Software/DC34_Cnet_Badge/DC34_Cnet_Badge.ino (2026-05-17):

// ESP32 + GC9A01 (round 240x240), microSD, RC522 RFID, Animated GIF player with RFID switching
// Plays a GIF on the round TFT, switches GIF when a tag is presented.
//
// Board: ESP32 Dev Module
// PSRAM: Disabled

#include <esp_system.h>   // for esp_random() seed
#include <SPI.h>
#include <SD.h>
#include <FS.h>
#include <Adafruit_GFX.h>
#include <Adafruit_GC9A01A.h>
#include <AnimatedGIF.h>
#include <MFRC522.h>

// ---------- Pin assignments (your wiring) ----------
#define TFT_CS   5
#define TFT_DC   2
#define TFT_RST  4     // set to -1 if your module auto-resets
#define TFT_BL   -1    // backlight not controlled (set to a pin if supported)

#define SD_CS    13

#define RFID_SS  21    // RC522 "SDA"/SS
#define RFID_RST 22

// VSPI pins (ESP32 DevKit): SCK=18, MISO=19, MOSI=23
#define SPI_SCK  18
#define SPI_MISO 19
#define SPI_MOSI 23
// -----------------------------------------------------------------

// Display
Adafruit_GC9A01A tft(TFT_CS, TFT_DC, TFT_RST);

// RFID
MFRC522 rfid(RFID_SS, RFID_RST);

// GIF decoder
AnimatedGIF gif;

// Playback state
static const char *DEFAULT_GIF = "/_startup_240x240.gif";
String currentGifPath = DEFAULT_GIF;
String lastUID = "";
unsigned long lastSwitchMs = 0;   // debounce

// Centering offsets for the GIF on the 240x240 display
int16_t gifXOffset = 0, gifYOffset = 0;

// A small line buffer for pushing one scanline at a time to the TFT
static uint16_t lineBuf[240];

// ---------- Tag → GIF mapping (edit these for your tags) ----------
struct TagMap { const char *uid; const char *path; };
// Use UIDs exactly as printed (uppercase hex, colon-separated).
TagMap tagMap[] = {
  // {"DE:AD:BE:EF",          "/deadbeef.gif"},
  // {"01:E4:1A:A2",          "/Virus_2_240x240.gif"},
  // {"2A:BD:A4:CD",          "/Virus_3_240x240.gif"},
  // {"61:E9:F8:A3",          "/rick_roll_240x240.gif"},
  // {"0A:9E:C4:CD",          "/matt_damon_240x240.gif"},
};
const size_t tagMapCount = sizeof(tagMap)/sizeof(tagMap[0]);
// ------------------------------------------------------------------

// ------------------ AnimatedGIF file I/O (v2.x) -------------------
void* GIFOpenFile(const char *fname, int32_t *pSize) {
  File *pf = new File;
  *pf = SD.open(fname, FILE_READ);
  if (!(*pf)) { delete pf; return nullptr; }
  *pSize = pf->size();
  return (void*)pf;
}

void GIFCloseFile(void *pHandle) {
  File *pf = (File*)pHandle;
  if (pf) { pf->close(); delete pf; }
}

int32_t GIFReadFile(GIFFILE *pFile, uint8_t *pBuf, int32_t iLen) {
  File *pf = (File*)pFile->fHandle;
  if (!pf) return 0;
  int32_t bytes = pf->read(pBuf, iLen);
  pFile->iPos = pf->position();
  return bytes;
}

int32_t GIFSeekFile(GIFFILE *pFile, int32_t iPosition) {
  File *pf = (File*)pFile->fHandle;
  if (!pf) return -1;
  pf->seek(iPosition);
  pFile->iPos = iPosition;
  return iPosition;
}
// -------------------------------------------------------------------

// ------------- AnimatedGIF line-drawing callback -------------------
void GIFDraw(GIFDRAW *pDraw) {
  int16_t x = pDraw->iX + gifXOffset;
  int16_t y = pDraw->iY + pDraw->y + gifYOffset;
  int16_t w = pDraw->iWidth;
  if (w <= 0) return;

  // Clip
  if (x >= tft.width() || y < 0 || y >= tft.height()) return;
  if (x + w > tft.width()) w = tft.width() - x;

  uint8_t  *s   = pDraw->pPixels;           // 8-bit indices
  uint16_t *pal = (uint16_t*)pDraw->pPalette; // RGB565 (LE, we set in gif.begin)

  int16_t runStart = -1;
  for (int16_t i = 0; i < w; i++) {
    uint8_t idx = s[i];
    bool transparent = pDraw->ucHasTransparency && (idx == pDraw->ucTransparent);
    if (!transparent) {
      if (runStart < 0) runStart = i;
      lineBuf[i - runStart] = pal[idx];
    }
    bool endRun = (runStart >= 0) && (transparent || i == (w - 1));
    if (endRun) {
      int16_t runLen = i - runStart + (transparent ? 0 : 1);
      tft.startWrite();
      tft.setAddrWindow(x + runStart, y, runLen, 1);
      tft.writePixels(lineBuf, runLen, false);
      tft.endWrite();
      runStart = -1;
    }
  }
}
// -------------------------------------------------------------------

// ----------------- Helpers: UID → string / path --------------------
String uidToString(const MFRC522::Uid &uid) {
  String s; s.reserve(uid.size * 3);
  for (byte i = 0; i < uid.size; i++) {
    if (uid.uidByte[i] < 0x10) s += '0';
    s += String(uid.uidByte[i], HEX);
    if (i + 1 < uid.size) s += ':';
  }
  s.toUpperCase();
  return s;
}

String removeColons(const String &u) {
  String out; out.reserve(u.length());
  for (size_t i = 0; i < u.length(); i++) if (u[i] != ':') out += u[i];
  return out;
}


String mappedPathForUID(const String &uidStr) {
  // 1) explicit map
  for (size_t i = 0; i < tagMapCount; i++) {
    if (uidStr.equals(tagMap[i].uid)) return String(tagMap[i].path);
  }
  // 2) per-UID fallback file if present: "/<UID_NO_COLONS>.gif"
  String candidate = "/" + removeColons(uidStr) + ".gif";
  if (SD.exists(candidate)) return candidate;

  // 3) persistent random assignment for unknown tag
  return getOrAssignRandomGifForUID(uidStr);
}


/*
String mappedPathForUID(const String &uidStr) {
  // 1) explicit map
  for (size_t i = 0; i < tagMapCount; i++) {
    if (uidStr.equals(tagMap[i].uid)) return String(tagMap[i].path);
  }
  // 2) fallback: "/<UID_NO_COLONS>.gif" if it exists
  String candidate = "/" + removeColons(uidStr) + ".gif";
  if (SD.exists(candidate)) return candidate;
  // 3) else keep current or default
  return String(DEFAULT_GIF);
}
*/


// --- config for random assignment ---
static const char *MAP_FILE   = "/rfid_map.txt";  // persistent UID→path map
static const char *RANDOM_DIR = "/";              // where to look for GIFs (use "/" or "/gifs")

// Case-insensitive .gif check
bool endsWithNoCase(const String &s, const char *suffix) {
  int sl = s.length(), tl = strlen(suffix);
  if (tl > sl) return false;
  for (int i = 0; i < tl; i++) {
    char a = s[sl - tl + i], b = suffix[i];
    if (a >= 'A' && a <= 'Z') a += 32;
    if (b >= 'A' && b <= 'Z') b += 32;
    if (a != b) return false;
  }
  return true;
}

// Choose a random GIF in RANDOM_DIR, excluding DEFAULT_GIF.
// Uses reservoir sampling so we don't store all filenames.
String chooseRandomGif() {
  File dir = SD.open(RANDOM_DIR);
  if (!dir || !dir.isDirectory()) return String();

  String chosen = "";
  uint32_t seen = 0;

  for (File f = dir.openNextFile(); f; f = dir.openNextFile()) {
    if (f.isDirectory()) { f.close(); continue; }

    String name = String(f.name());
    f.close();

    // Build a full path (name may or may not start with '/')
    String path = name.startsWith("/") ? name : (String(RANDOM_DIR) + (String(RANDOM_DIR).endsWith("/") ? "" : "/") + name);

    if (!endsWithNoCase(path, ".gif")) continue;
    if (path.equalsIgnoreCase(DEFAULT_GIF)) continue;  // don't assign default

    // reservoir sampling: replace with 1/++seen probability
    seen++;
    uint32_t r = random(seen); // 0..seen-1
    if (r == 0) chosen = path;
  }
  dir.close();
  return chosen; // may be empty if none found
}

// Look up existing assignment from /rfid_map.txt (format: UID=/path.gif)
String loadAssignedPath(const String &uidStr) {
  if (!SD.exists(MAP_FILE)) return String();
  File f = SD.open(MAP_FILE, FILE_READ);
  if (!f) return String();

  String line, result;
  while (f.available()) {
    line = f.readStringUntil('\n');
    line.trim();
    if (line.length() == 0) continue;
    int eq = line.indexOf('=');
    if (eq <= 0) continue;
    String uid = line.substring(0, eq);
    String path = line.substring(eq + 1);
    uid.trim(); path.trim();
    if (uid.equalsIgnoreCase(uidStr)) { result = path; break; }
  }
  f.close();
  return result;
}

// Append new assignment UID=/path.gif
bool appendAssignment(const String &uidStr, const String &path) {
  File f = SD.open(MAP_FILE, FILE_APPEND);
  if (!f) {
    // fallback: create and append
    f = SD.open(MAP_FILE, FILE_WRITE);
    if (!f) return false;
    f.seek(f.size());
  }
  f.print(uidStr); f.print('='); f.println(path);
  f.close();
  return true;
}

// Public: get or assign a random GIF for an unknown UID
String getOrAssignRandomGifForUID(const String &uidStr) {
  // If we already have a saved mapping, use it (and ensure file still exists)
  String saved = loadAssignedPath(uidStr);
  if (saved.length() && SD.exists(saved)) return saved;

  // Otherwise, pick a random GIF from RANDOM_DIR
  String rnd = chooseRandomGif();
  if (rnd.length() == 0) {
    Serial.println("[MAP] No GIFs found for random assignment. Using default.");
    return String(DEFAULT_GIF);
  }

  // Persist the new mapping
  if (appendAssignment(uidStr, rnd)) {
    Serial.print("[MAP] Assigned "); Serial.print(uidStr); Serial.print(" -> "); Serial.println(rnd);
  } else {
    Serial.println("[MAP] Failed to save mapping file; using random path transiently.");
  }
  return rnd;
}


// -------------------------------------------------------------------

/**
// Returns true if a *new* tag selected a *different* GIF (so caller can switch)
bool checkRFIDAndMaybeSwitch() {
  if (!(rfid.PICC_IsNewCardPresent() && rfid.PICC_ReadCardSerial())) return false;

  String uidStr = uidToString(rfid.uid);
  rfid.PICC_HaltA();
  rfid.PCD_StopCrypto1();

  // debounce: ignore the same UID spam for 1s unless it picks a new file
  unsigned long now = millis();
  bool allow = (uidStr != lastUID) || (now - lastSwitchMs > 1000);

  String newPath = mappedPathForUID(uidStr);
  bool isNewGif = (newPath != currentGifPath);

  if (allow && isNewGif) {
    Serial.print("RFID UID: "); Serial.println(uidStr);
    Serial.print("Switching to: "); Serial.println(newPath);
    currentGifPath = newPath;
    lastUID = uidStr;
    lastSwitchMs = now;
    return true;
  }
  return false;
}
*/

// Prints every scan. Only debounces the *switching* of GIFs.
bool checkRFIDAndMaybeSwitch() {
  if (!(rfid.PICC_IsNewCardPresent() && rfid.PICC_ReadCardSerial())) return false;

  String uidStr  = uidToString(rfid.uid);
  String newPath = mappedPathForUID(uidStr);

  // Always print each scan
  Serial.print("[SCAN] UID: "); Serial.println(uidStr);
  Serial.print("[SCAN] Candidate GIF: "); Serial.println(newPath);

  bool isNewGif = (newPath != currentGifPath);
  unsigned long now = millis();
  bool switchAllowed = isNewGif && (uidStr != lastUID || (now - lastSwitchMs > 1000));

  // tidy up the RF field session
  rfid.PICC_HaltA();
  rfid.PCD_StopCrypto1();

  if (switchAllowed) {
    Serial.println("[SCAN] Switching GIF.");
    currentGifPath = newPath;
    lastUID = uidStr;
    lastSwitchMs = now;
    return true;  // tell the player loop to break and reopen
  } else {
    if (!isNewGif) Serial.println("[SCAN] No switch (same GIF).");
    else           Serial.println("[SCAN] Switch suppressed by debounce.");
    // still record the last UID so debounce logic works, but printing always happens
    lastUID = uidStr;
    return false;
  }
}



// Play currentGifPath until it ends OR an RFID switch is requested.
// Returns true if it switched mid-playback.
bool playCurrentGifUntilSwitch() {
  if (!gif.open(currentGifPath.c_str(), GIFOpenFile, GIFCloseFile, GIFReadFile, GIFSeekFile, GIFDraw)) {
    tft.fillScreen(0x0000);
    tft.setTextColor(0xFFFF); tft.setTextSize(2);
    tft.setCursor(10, 110);
    tft.print("Open fail:");
    tft.setCursor(10, 130);
    tft.print(currentGifPath);
    Serial.print("Failed to open "); Serial.println(currentGifPath);
    delay(1500);
    // fallback to default if current is bad
    if (currentGifPath != DEFAULT_GIF) currentGifPath = DEFAULT_GIF;
    return false;
  }

  // Center the GIF on the 240x240 round display
  gifXOffset = (tft.width()  - gif.getCanvasWidth())  / 2;
  gifYOffset = (tft.height() - gif.getCanvasHeight()) / 2;

  // Clear background
  tft.fillScreen(0x0000);

  bool switched = false;
  while (gif.playFrame(true, nullptr)) {
    yield();
    if (checkRFIDAndMaybeSwitch()) { switched = true; break; }
  }

  gif.close();
  return switched;
}

void setup() {
  // Keep all CS lines deasserted
  pinMode(TFT_CS, OUTPUT); digitalWrite(TFT_CS, HIGH);
  pinMode(SD_CS,  OUTPUT); digitalWrite(SD_CS,  HIGH);
  pinMode(RFID_SS,OUTPUT); digitalWrite(RFID_SS,HIGH);

  if (TFT_BL >= 0) { pinMode(TFT_BL, OUTPUT); digitalWrite(TFT_BL, HIGH); }

  Serial.begin(115200);
  delay(200);

  randomSeed(esp_random());  // good entropy on ESP32

  // Shared SPI bus
  SPI.begin(SPI_SCK, SPI_MISO, SPI_MOSI);

  // Start TFT
  tft.begin(40000000);         // try 80000000 if your module tolerates it
  tft.setRotation(0);
  tft.fillScreen(0x0000);

  // Start SD
  if (!SD.begin(SD_CS, SPI, 20000000)) {
    tft.setTextColor(0xFFFF); tft.setTextSize(2);
    tft.setCursor(10, 110);
    tft.print("SD init failed");
    Serial.println("SD init failed. Check wiring and SD_CS.");
    while (true) { delay(1000); }
  }

  // Start RC522
  rfid.PCD_Init(RFID_SS, RFID_RST);
  Serial.println("RC522 ready.");

  // GIF palette endianness (you found LE works best)
  gif.begin(GIF_PALETTE_RGB565_LE);
  // If available in your lib version, you can also:
  // gif.setDrawType(GIF_DRAW_COOKED);

  Serial.println("Setup complete. Tap a tag to switch GIFs.");
}

void loop() {
  // Play until end, then loop. If a tag switches mid-playback, it returns early.
  playCurrentGifUntilSwitch();
}

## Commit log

2025-10-07 Reorg File Structure
    [DC34_Cnet_Badge_Main.kicad_pcb, DC34_Cnet_Badge_Main.kicad_sch, DC34_Cnet_Badge_SAO.kicad_pcb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]
2025-11-04 PCB Updates
    [DC34_Cnet_Badge_Main-B_Cu.gbr, DC34_Cnet_Badge_Main-B_Mask.gbr, DC34_Cnet_Badge_Main-B_Paste.gbr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]
2026-01-15 Incremental updates
    [DC34_Cnet_Badge_Main.kicad_pcb]
2026-02-03 Revert "Test commit adding a read indicator"
    This reverts commit 26a82adc6ce89803800c12d37040e3a8396e78dc.
    [DC34_Cnet_Badge.ino]
2026-03-23 Alternate Layout
    Alternate Layout
    [DC34_Cnet_Badge_Main.kicad_pcb]
2026-03-23 Version 2
    Version 2 Layout
    [DC34_Cnet_Badge_Main.kicad_pcb]
2026-04-28 Traces run
    [DC34_Cnet_Badge_Main-B_Cu.gbr, DC34_Cnet_Badge_Main-B_Mask.gbr, DC34_Cnet_Badge_Main-B_Paste.gbr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]
2026-05-01 Change to alkaline batts and art updates
    [DC34_Cnet_Badge_Main-B_Cu.gbr, DC34_Cnet_Badge_Main-B_Mask.gbr, DC34_Cnet_Badge_Main-B_Paste.gbr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]
2026-05-15 Updated slide images
    [DC34_Cnet_Badge_Main-B_Cu.gbr, DC34_Cnet_Badge_Main-B_Mask.gbr, DC34_Cnet_Badge_Main-B_Paste.gbr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]
2026-05-17 PCB and Image updates
    [Slide-Body.3mf, Slide-Body.stl, Slide.FCStd]
2026-05-28 Fixed PCB SAO GND error
    [DC34_Cnet_Badge_Main-B_Cu.gbr, DC34_Cnet_Badge_Main-B_Mask.gbr, DC34_Cnet_Badge_Main-B_Paste.gbr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]
2026-06-02 Add slide images
    [DC34_Cnet_Badge_BoMs.xlsx]
2026-06-04 Final PCB updates
    [DC34_Cnet_Badge_BoMs.xlsx, DC34_Stand-Body.3mf, DC34_Stand-Body.stl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]
2026-06-05 Final BoM updates
    [DC34_Cnet_Badge_BoMs.xlsx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]
2026-06-05 Clean up
    [DC34_Cnet_Badge_BoMs.xlsx]
2026-06-26 Updated startup gif
    [DC34_Stand-Body.3mf]
2026-07-27 Remove Private
    [DC34_Cnet_Badge_BoMs.xlsx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]
